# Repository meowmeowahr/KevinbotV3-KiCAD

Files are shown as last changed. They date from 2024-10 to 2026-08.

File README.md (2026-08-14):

# This repository has moved

Kevinbot Core and the Kevinbot P2 Board have split into separate repositories, and are now located in the [Kevinbot Robotics](https://github.com/Kevinbot-Robotics) organization.

## Kevinbot Core (aka RevB)

https://github.com/Kevinbot-Robotics/kevinbot_core

## Kevinbot P2 Board (aka RevA)

https://github.com/Kevinbot-Robotics/kevinbot_p2_board

## PCBWay

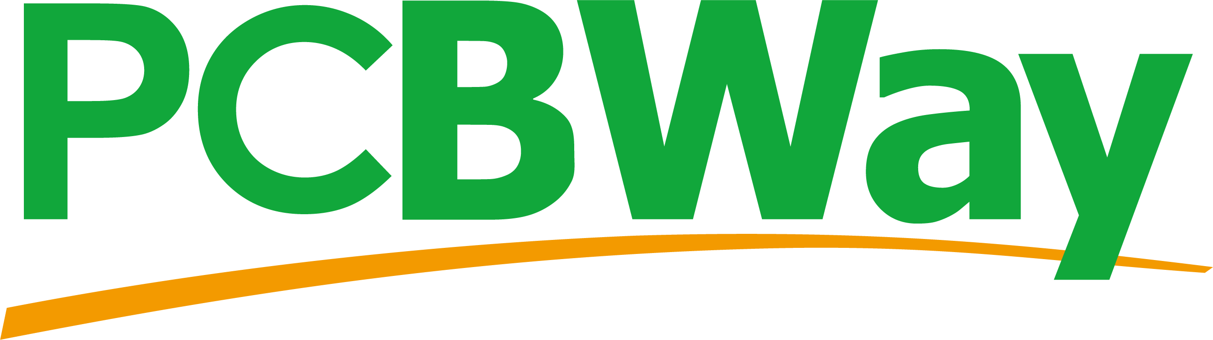
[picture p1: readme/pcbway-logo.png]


Thanks to PCBWay for providing high-quality PCB prototypes.

I would recommend them for any of your PCB needs. They offer fast turnaround and shipping.

[Get a Quote Here](https://www.pcbway.com/orderonline.aspx)

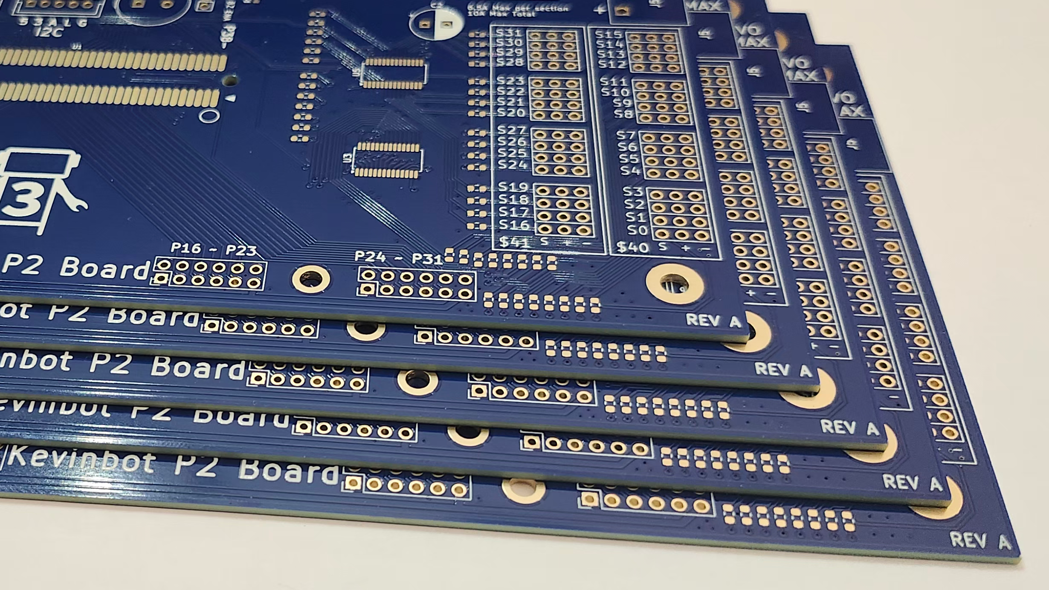
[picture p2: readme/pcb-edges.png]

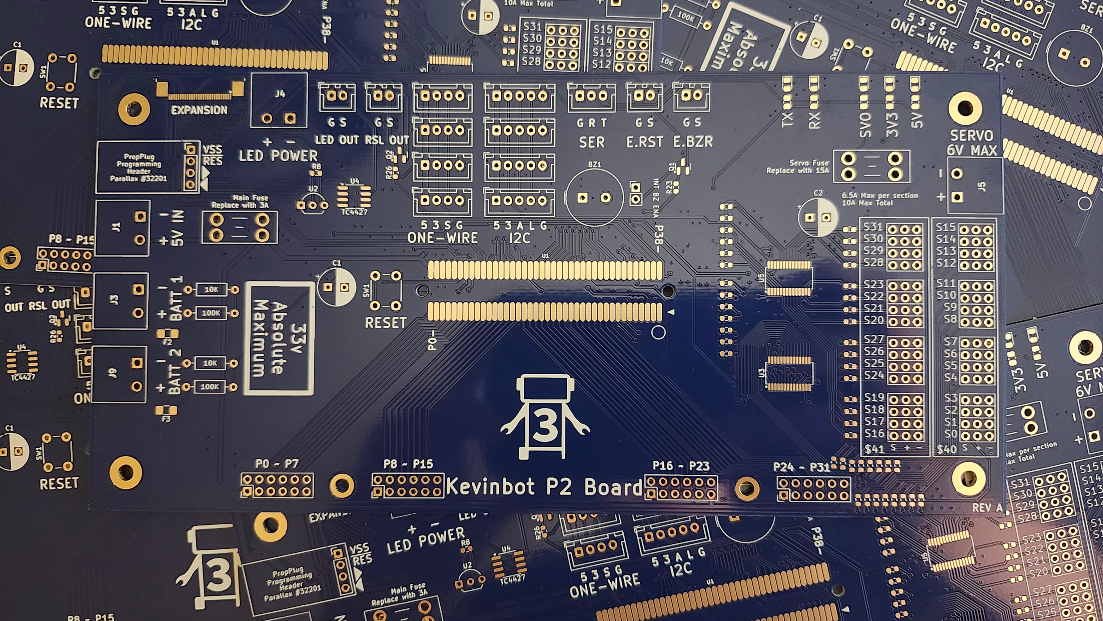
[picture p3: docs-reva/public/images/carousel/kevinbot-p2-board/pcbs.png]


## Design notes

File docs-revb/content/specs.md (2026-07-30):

---
title: "Specifications"
editURL: https://github.com/meowmeowahr/KevinbotV3-KiCAD/edit/RevB/docs/specs.md
cascade:
  type: docs
weight: 3
---

## Electrical Characteristics

| Parameter | <div style="width:200px">Name</div>  | <div style="width:100px">Conditions</div> | Min | Typical | Max | Unit |
| --- | --- | --- | --- | --- | --- | ---- |
| V<sub>IN</sub> | Input Voltage | | 6 | - | 40 | V |
| I<sub>DD</sub> | Input Current Draw | V<sub>IN</sub> = 6V<br>V<sub>IN</sub> = 23V<br>V<sub>IN</sub> = 40V | - | - | 5.30<br>1.40<br>0.82 | A |
| V<sub>IN(VM)</sub> | Voltmeter Input Voltage | | - | - | 60 | V |
| I<sub>DD(VM)</sub> | Voltmeter Current Draw | V<sub>IN(VM)</sub> = 60V<br>V<sub>IN(VM)</sub> = 12V<br>V<sub>IN(VM)</sub> = 6V | - | 315.8<br>63.2<br>31.6 | - | µA |
| V<sub>IN(SV)</sub> | Servo Input Voltage | | - | - | 24 | V |
| I<sub>OUT(SV)</sub> | Servo Max Total Output Current | | - | - | 12 | A |
| I<sub>OUT(SVCH)</sub> | Servo Max Per Channel Output Current | | - | - | 3 | A |

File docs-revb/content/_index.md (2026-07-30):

---
title: "Kevinbot Core"
editURL: https://github.com/meowmeowahr/KevinbotV3-KiCAD/edit/RevB/docs-revb/content/_index.md
cascade:
  type: docs
next: diagram
---

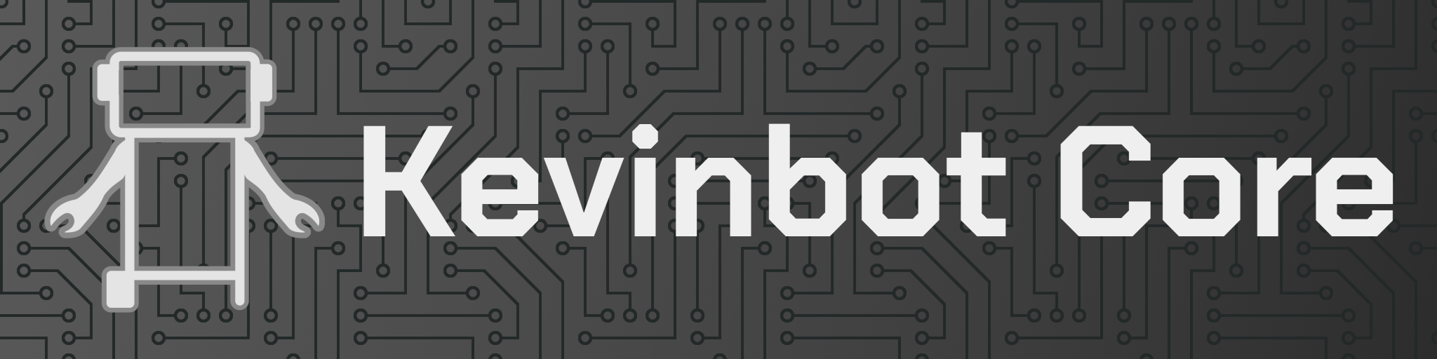
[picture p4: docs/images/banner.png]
Logo banner


<style>
/* hide title */
article > main > div.content > :nth-child(1) {
    display: none;
}
</style>

{{< carousel gallery="kevinbot-core" >}}

{{< hextra/hero-button text="View Project on GitHub" link="https://github.com/meowmeowahr/KevinbotV3-KiCAD/tree/RevB" >}}

The Kevinbot Core is a [Parallax Propeller 2 Edge](https://www.parallax.com/product/p2-edge-module/) Breakout 
Board catered for robotics use.
Originally designed only for use in Kevinbot v3, the board can be used for any P2-based robotics project.

## Revision Comparisons

| Feature | RevA | RevB |
| :--- | :--- | :--- |
| MCU | Parallax P2 | Parallax P2 |
| Input Voltage | 5V | 6V ~ 40V |
| I/O Pins | 32 (Accessory), 20 (Expansion) | 32 (Accessory) |
| Servo Ports | 32 (Up to 6V power) | 16 (Up to 24V power) |
| Interfaces | UART, I2C, One-Wire | RS-422 (_or_ UART), I2C, One-Wire |
| Serial Interface | ✅ UART | ✅ RS-422 (_or_ UART) |
| I2C Interface | ✅ 4 Ports | ✅ 1 Port with Active Pullup |
| One-Wire Interface | ✅ 4 Ports | ✅ 1 Port with Active Pullup |
| Programming | PropPlug Interface | USB-C _or_ External |
| Inbuilt Sensors | DS18B20 Thermo | DS18B20 Thermo |
| Voltmeters | 2x Up to 33v | 2x Up to 60v + Input meter (Up to 40v) |
| Error Buzzer | ✅ | ✅ |
| NeoPixel Output | ✅ | ✅ |
| Status Light Output | ✅ | ✅ |
| Reset Button and Header | ✅ | ✅ |

## Specifications

* Compatible with standard P2 Edge (will not work with the 32 MB option)
* USB-C FTDI Programming Interface
* 16 Servo Outputs
* One-Wire with Active Pullup
* I2C with Active Pullup
* RS-422
* Status Light Port
* Internal Input Voltmeter (1v ~ 40v) + Two External Voltmeters (1v ~ 60v)
* Level-Shifted Addressable LED port
* Four 2x6 P2 accessory headers
* Internal and External Error Buzzer
* Reset Button and External Reset button port
* Internal DS18b20 thermometer
* Fully Open Source Design

## License

All hardware is licensed under the CERN-OHL-S-2.0 license. 
Documentation and media (images) are licensed under a CC-BY-SA-4.0 license.

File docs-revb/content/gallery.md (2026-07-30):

---
title: "Image Gallery"
editURL: https://github.com/meowmeowahr/KevinbotV3-KiCAD/edit/RevB/docs-revb/content/gallery.md
cascade:
  type: docs
weight: 7
---

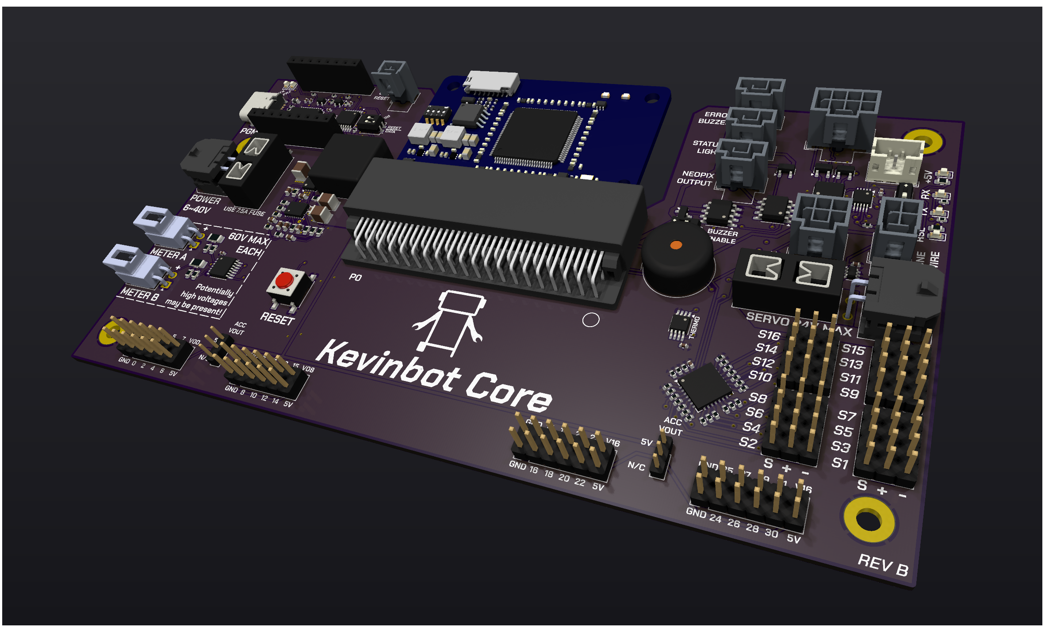
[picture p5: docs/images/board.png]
tbd


## 3D Renders

### Black

{{< tabs >}}
    {{< tab name="Angle 1" >}}
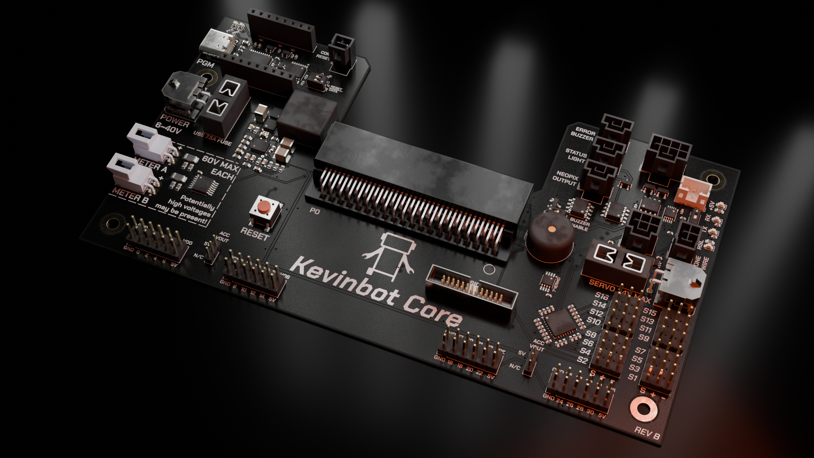
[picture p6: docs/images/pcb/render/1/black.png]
    
    {{< /tab >}}
    {{< tab name="Angle 2" >}}
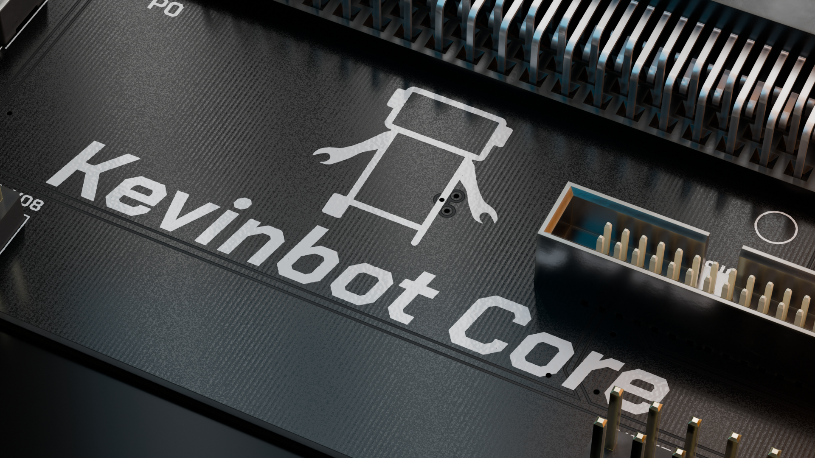
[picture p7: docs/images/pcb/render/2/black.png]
    
    {{< /tab >}}
{{< / tabs >}}

### White

{{< tabs >}}
    {{< tab name="Angle 1" >}}
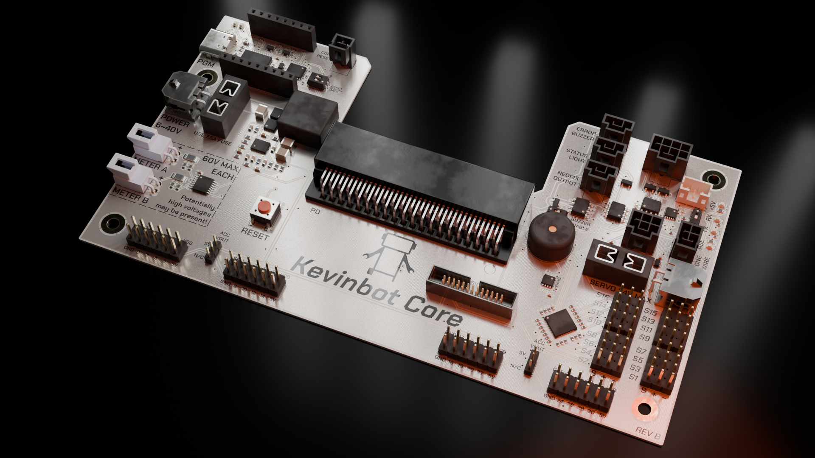
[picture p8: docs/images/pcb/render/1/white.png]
    
    {{< /tab >}}
    {{< tab name="Angle 2" >}}
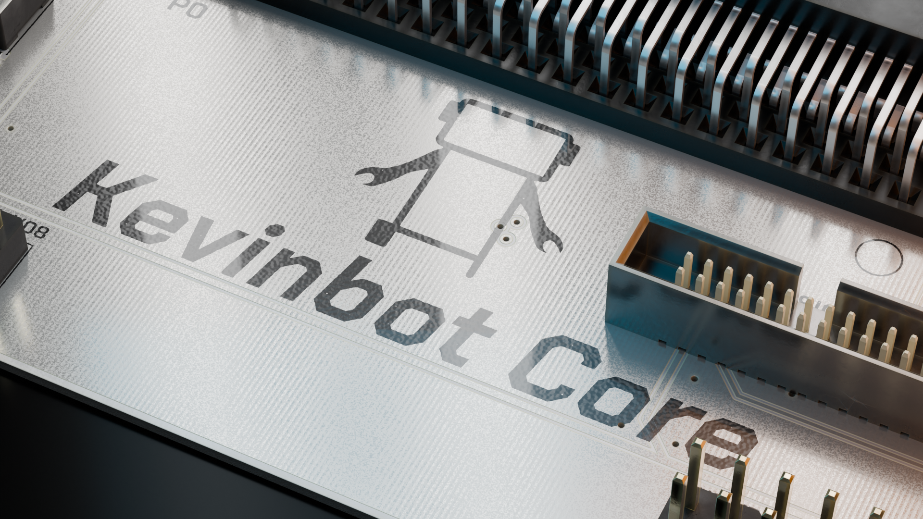
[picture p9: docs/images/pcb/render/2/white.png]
    
    {{< /tab >}}
{{< / tabs >}}

### Blue

{{< tabs >}}
    {{< tab name="Angle 1" >}}
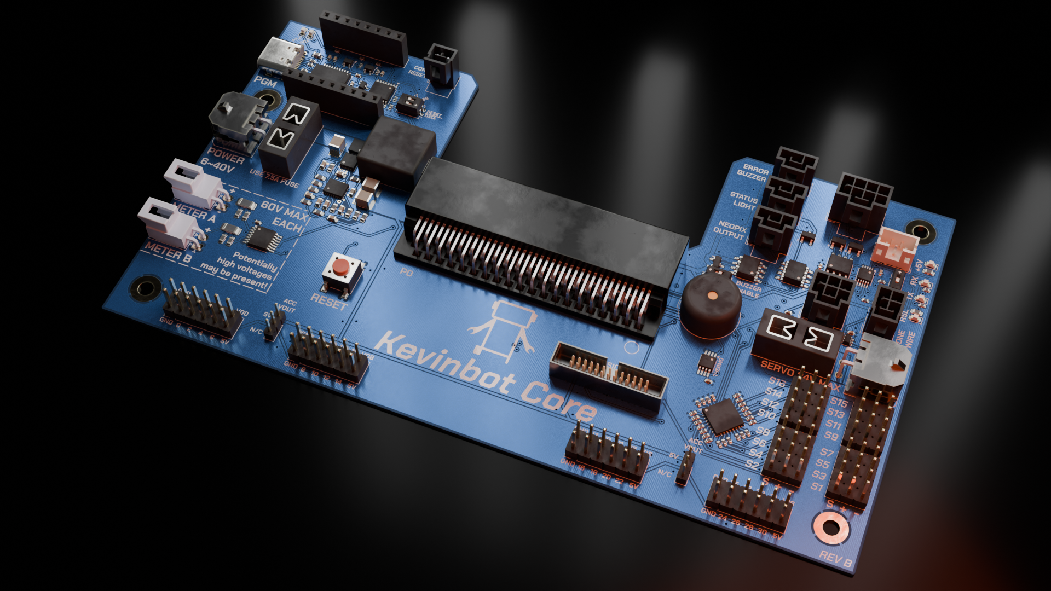
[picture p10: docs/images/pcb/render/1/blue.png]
    
    {{< /tab >}}
    {{< tab name="Angle 2" >}}
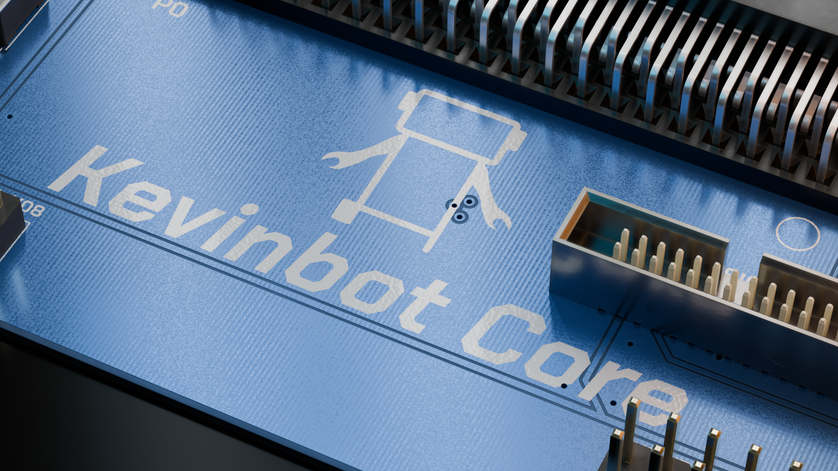
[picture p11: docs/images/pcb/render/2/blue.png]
    
    {{< /tab >}}
{{< / tabs >}}

### Green

{{< tabs >}}
    {{< tab name="Angle 1" >}}
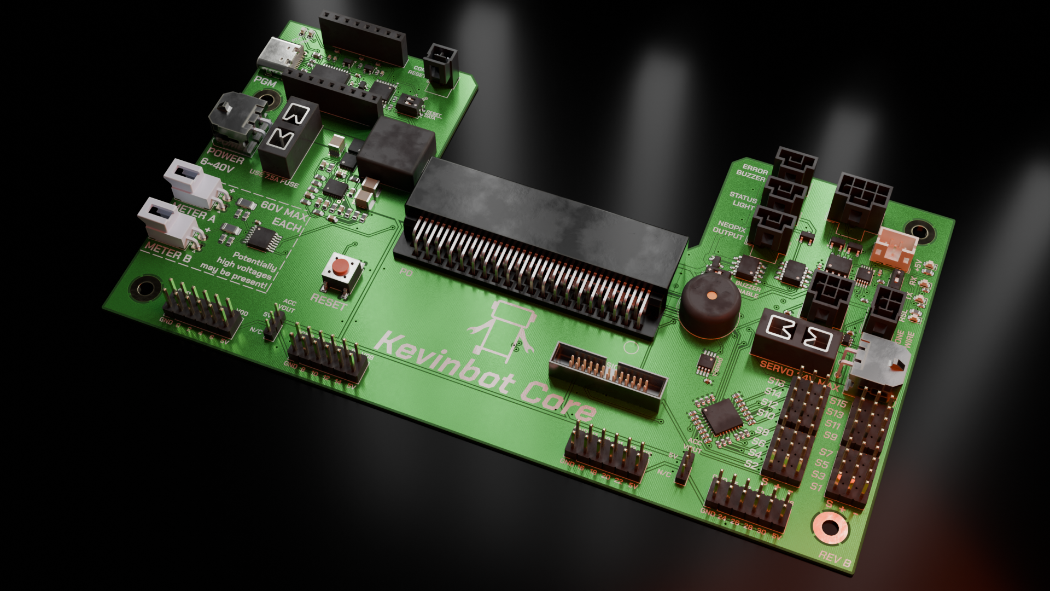
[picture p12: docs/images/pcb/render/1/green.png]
    
    {{< /tab >}}
    {{< tab name="Angle 2" >}}
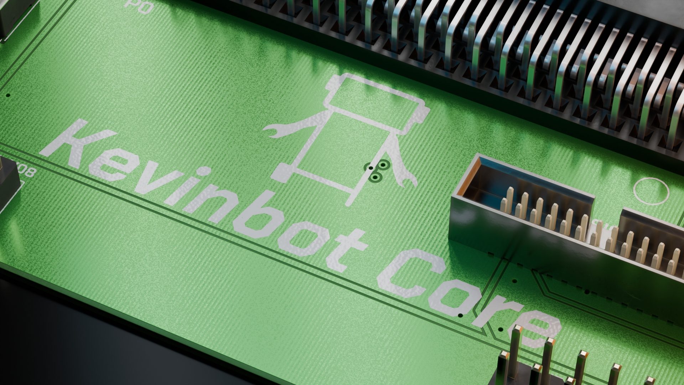
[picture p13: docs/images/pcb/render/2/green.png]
    
    {{< /tab >}}
{{< / tabs >}}

### Red

{{< tabs >}}
    {{< tab name="Angle 1" >}}
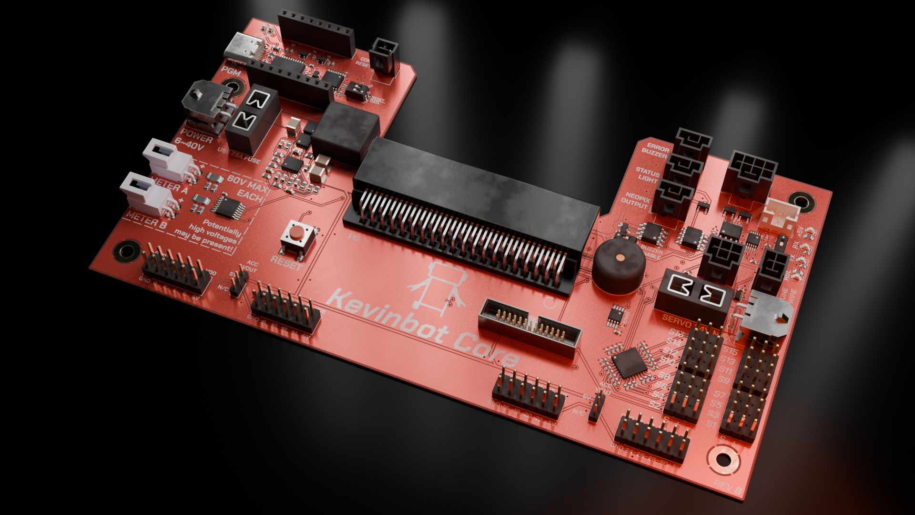
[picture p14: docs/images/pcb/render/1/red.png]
    
    {{< /tab >}}
    {{< tab name="Angle 2" >}}
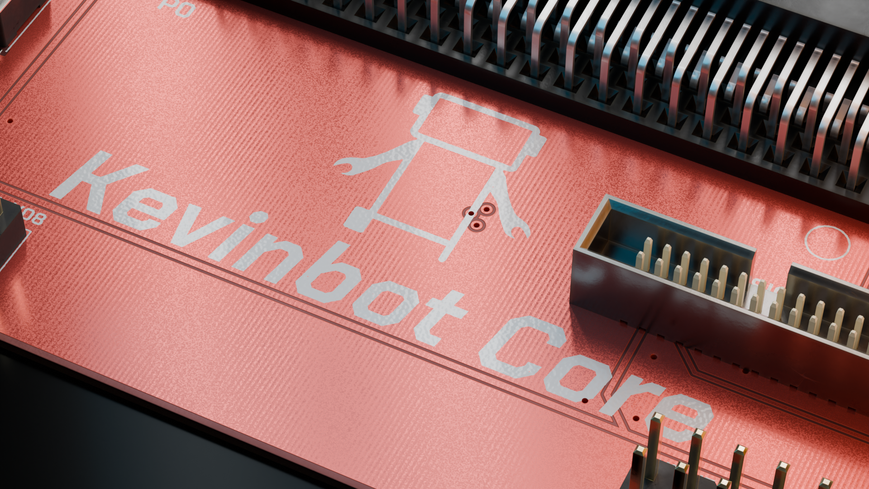
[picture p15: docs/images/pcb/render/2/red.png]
    
    {{< /tab >}}
{{< / tabs >}}

### Purple

{{< tabs >}}
    {{< tab name="Angle 1" >}}
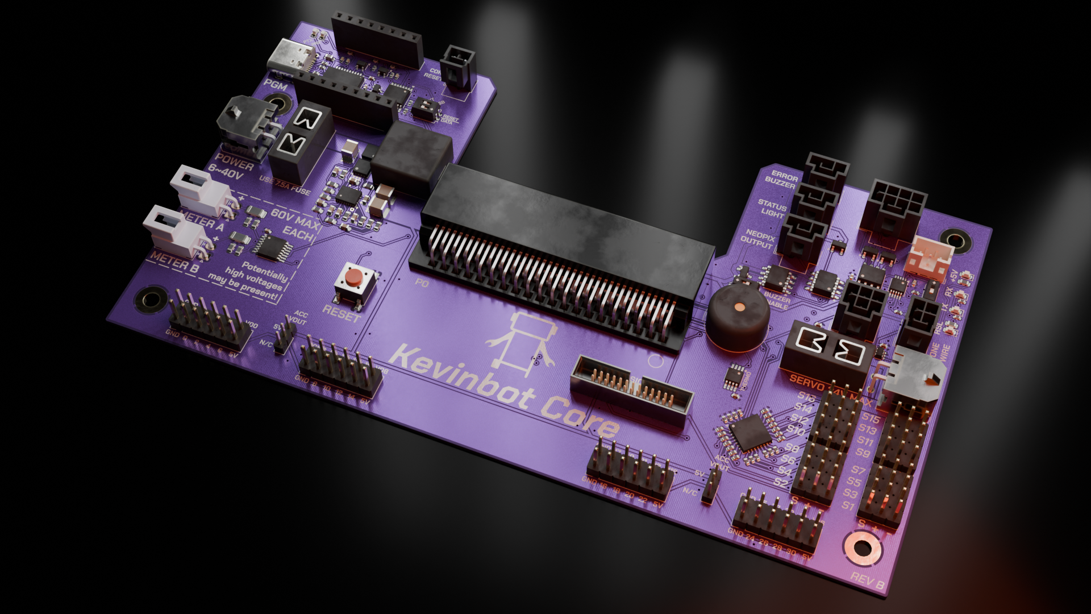
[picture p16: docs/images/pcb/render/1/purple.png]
    
    {{< /tab >}}
    {{< tab name="Angle 2" >}}
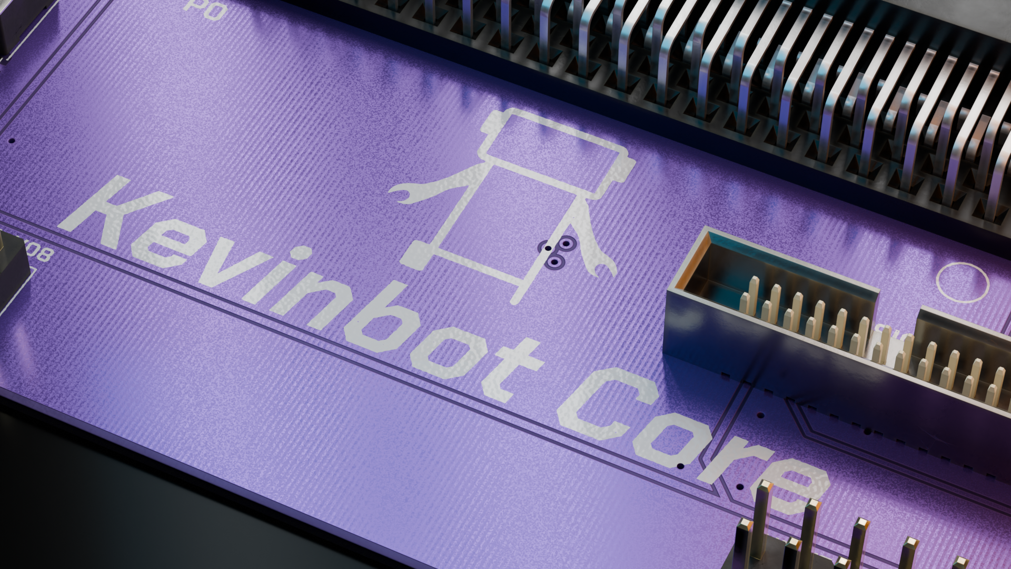
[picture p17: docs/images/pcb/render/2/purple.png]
    
    {{< /tab >}}
{{< / tabs >}}

### Yellow

{{< tabs >}}
    {{< tab name="Angle 1" >}}
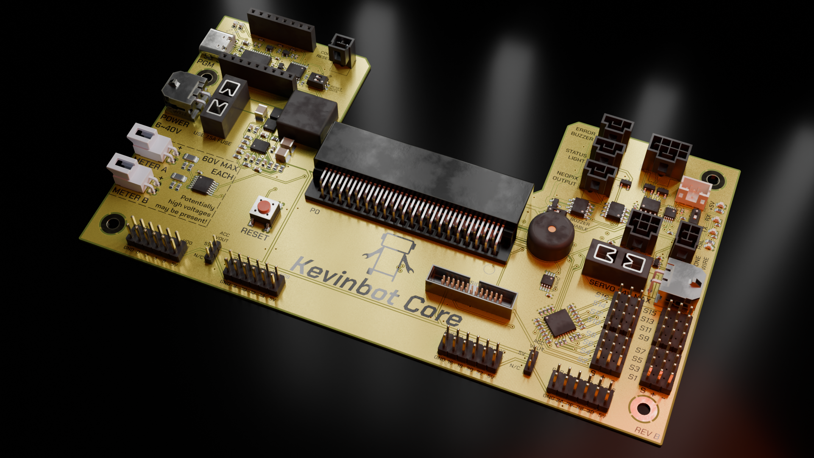
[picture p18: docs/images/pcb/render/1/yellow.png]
    
    {{< /tab >}}
    {{< tab name="Angle 2" >}}
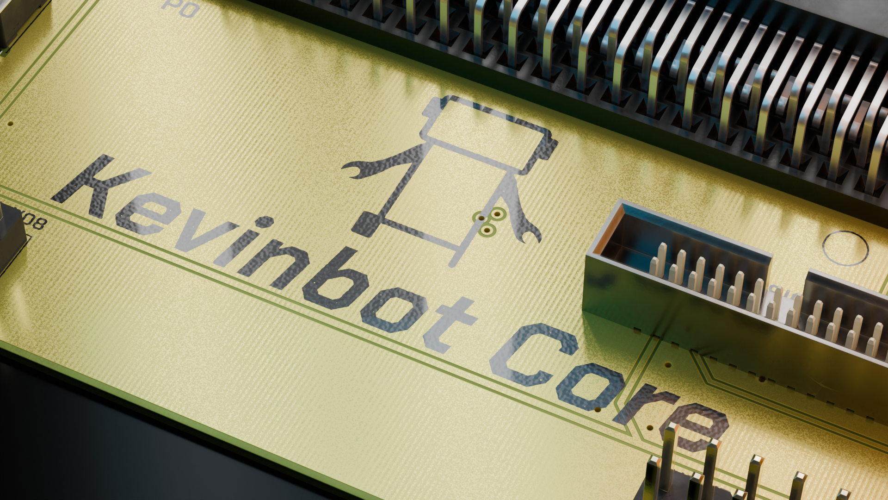
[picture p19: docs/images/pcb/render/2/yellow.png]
    
    {{< /tab >}}
{{< /tabs >}}

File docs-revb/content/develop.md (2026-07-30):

---
title: "Development"
editURL: https://github.com/meowmeowahr/KevinbotV3-KiCAD/edit/RevB/docs/develop.md
cascade:
  type: docs
weight: 8
---

## Technical

### Board and Schematics

The project utilizes KiCAD 9.0.1 or later.
Download it [here](https://www.kicad.org/download/).

The project file is located at `P2 Kevinbot Board.kicad_pro`

#### Fonts

The Kevinbot Core PCB design utilizes some non-standard fonts. They must be installed in the system to function correctly within KiCAD.

Restart KiCAD after installing fonts.

All utilized fonts are licensed under the [OFL (SIL Open Font License)](https://openfontlicense.org/)

[Chakra Petch :fontawesome-solid-arrow-up-right-from-square:](https://fonts.google.com/specimen/Chakra+Petch){ .md-button }

## Documentation

The Kevinbot Core documentation is built with [Hugo](https://gohugo.io/).

## WireViz

The Kevinbot Core documentation utilizes WireViz for cable harness visualizations.

### Install

Install Python dependencies using `pip`

```bash
pip install wireviz
```

### Develop

All WireViz YAML sources are located in the `wireviz/` directory.

Generated images are located in the `docs/images/wireviz/` directory.

Images can be generated with the `gen-harness` bash script.
Run it with the following.

```bash
bash tools/gen-harness.sh
```

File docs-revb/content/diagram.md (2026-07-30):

---
title: "Board Diagram"
editURL: https://github.com/meowmeowahr/KevinbotV3-KiCAD/edit/RevB/docs/diagram.md
cascade:
  type: docs
prev: /robotics/kevinbot-core
weight: 1
---

Numbered board diagram

## #1 - P2 Edge Socket
Compatible with Parallax P2 Edge ([https://www.parallax.com/product/p2-edge-module/](https://www.parallax.com/product/p2-edge-module/))

{{< callout type="warning" >}}
Kevinbot Core is **NOT** compatible with the *P2-EC32MB*
{{< /callout >}}

## #2 - Power Input
Kevinbot Core can take anywhere from 6v to 40v. Input is protected by a 7.5A fuse.
<br>
Operating outside these limits may cause damage to the board.

## #3 - USB-C Programming Header

FTDI Prop-Plug compatible programming interface.
<br>
Both [#21 DIP Switches](#21---programmer-selector-switches) must be set to **USB** to enable the USB programmer.

## #4 - Reset Button

Press the button to manually reset the P2

## #5 - Reset Header

Connect both pins to reset the P2.
<br>
Compatible with [Molex 1x2 Nano-Fit connector housings](https://www.molex.com/en-us/products/part-detail/1053071202)

## #6 - P2 EVAL Accessory Headers

Compatible with P2-EVAL accessories. Each header exposes 8 I/O pins, 3.3v, GND, and 5v.

## #7 - Accessory Header 5V Enable

Jumper selector to enable 5V on [#6 accessory headers](#6---p2-eval-accessory-headers)

## #8 - Expansion Port

Reserved for future use.

## #9 - Buzzer

User-controllable buzzer for errors, status, etc...

## #10 - Status Led Port

5v signal level LED header.

{{< callout type="note" >}}
It is not recommended to use this for addressable LEDs due to potential slow switching times.
{{< /callout >}}

## #11 - Addressable LED Output

5v signal level addressable LED output.

## #12 - RS-422 Input/Output

Serial over 2 twisted pairs. 

{{< callout type="note" >}}
The UART Enable Switch must be set to the lower position to enable the RS-422 port.
{{< /callout >}}

## #13 - UART Input/Output

3.3v UART RX/TX lines.

{{< callout type="note" >}}
The UART Enable Switch must be set to the upper position to enable the UART port.
{{< /callout >}}

## #14 - I2C Port

3.3v I2C SDA/SCL lines.

## #15 - One-Wire Port

3.3v One-Wire data.

## #16 - Servo Power Input

Up to 24v servo power input. Protected by a 15A fuse.
<br>
Operating outside these limits may cause damage to the board.

## #17 - Servo (PWM) Headers

16 PWM headers. Uses a PCA9685 to drive the outputs.

## #18 - Thermometer

DS18B20 One-Wire thermometer.
<br>
Internally connected to the same One-Wire bus as the [One-Wire Port](#15---one-wire-port)

## #19 - Programmer Indicator LEDs

FTDI activity LEDs.

## #20 - External Programmer Headers

Connection to external programming device. Exposes the P2's Rx/Tx, and flash chip SPI lines.
<br>
Both [#21 DIP Switches](#21---programmer-selector-switches) must be set to **EXT** to enable the USB programmer.

## #21 - Programmer Selector Switches

Switch between the USB-C and external programming headers.

## #22 - External Error Buzzer Port

External buzzer port with 5v signal level.

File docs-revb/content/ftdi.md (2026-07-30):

---
title: "FTDI Configuration"
editURL: https://github.com/meowmeowahr/KevinbotV3-KiCAD/edit/RevB/docs/ftdi.md
cascade:
  type: docs
weight: 5
---

The onboard FT231XS UART-to-USB converter requires configuration before it is able to program the P2.
Configuration is done through [FT_PROG](https://ftdichip.com/utilities/#ft_prog)

{{< callout type="warning" >}}
Incorrect usage of FT_PROG may brick the FT231XS chip. Be careful when changing settings.
{{< /callout >}}

## Settings

| Option | Value  |
| :--- | :----- |
| CBUS0 | TXLED  |
| CBUS1 | SLEEP# |
| CBUS2 | TXDEN  |
| CBUS2 | RXLED  |
| USB - MaxPower | 90mA |
| Pull down IO in suspend | True |

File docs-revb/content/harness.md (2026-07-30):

---
title: "Wiring Harnesses"
editURL: https://github.com/meowmeowahr/KevinbotV3-KiCAD/edit/RevB/docs/harness.md
cascade:
  type: docs
weight: 6
---

## Main RS-422 Communication

RS-422 Core<->System Cable Core represents the Kevinbot Core, System represents the main control system

### Cable Options

#### Tensility International Corp 30-02485

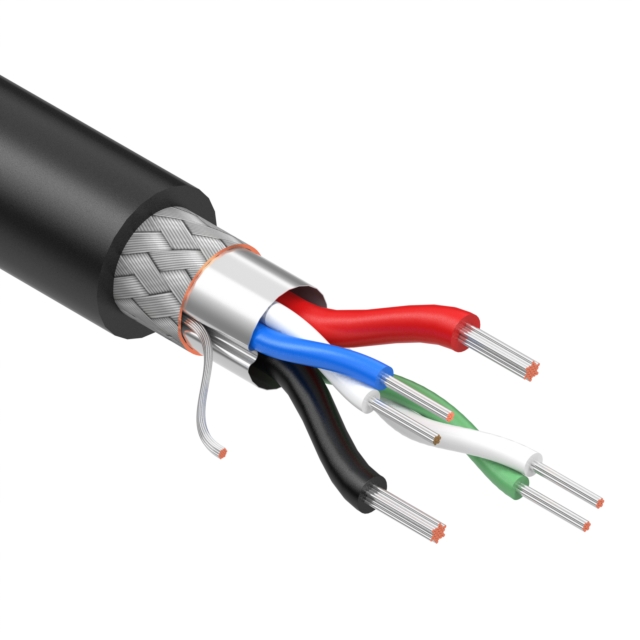
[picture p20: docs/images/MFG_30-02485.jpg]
Tensility International Corp 30-02485


[Digi-Key](https://www.digikey.com/en/products/detail/tensility-international-corp/30-02485/16629555)

The Blue/White Pair corresponds to GN/BU
<br>
The Green/White Pair corresponds to YE/OG
<br>
The Black and Red Wires are **BOTH** connected to GND at both ends
<br>
The Shield is connected at pin 8 of the System end

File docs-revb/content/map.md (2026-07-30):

---
title: "Pin Mappings"
editURL: https://github.com/meowmeowahr/KevinbotV3-KiCAD/edit/RevB/docs/map.md
cascade:
  type: docs
weight: 2
---

tbd

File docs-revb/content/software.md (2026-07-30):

---
title: "Software"
editURL: https://github.com/meowmeowahr/KevinbotV3-KiCAD/edit/RevB/docs/software.md
cascade:
  type: docs
weight: 4
---

## Board-specific applications

[**Kevinbot v3 Core**](https://github.com/meowmeowahr/KevinbotV3-HW-Core)

## General P2 Objects

**jm_ds18b20.spin2**
<br/>
A driver can be found [here](https://www.parallax.com/1-wire-driver-with-ds18b20-temperature-sensor-demo/)

This will work for interfacing with the single sensor on the board, or external sensors via the One-Wire Ports.
You can use the One-Wire scanner tool on the [Kevinbot v3 GitHub Repo](https://github.com/meowmeowahr/KevinbotV3-HW-Core/blob/v3-redesign/KevinbotV3_DS_SerialTool.spin2)

**ka_pca9685.spin2**
<br/>
The driver can be found [here](https://github.com/meowmeowahr/KevinbotV3-HW-Core/blob/v3-redesign/ka_pca9685.spin2)

This will work for the built in 16x servo controller, and any additional servo expansions

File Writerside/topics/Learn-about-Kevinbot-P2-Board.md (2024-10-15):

# Learn about Kevinbot P2 Board

The Kevinbot P2 Board is a [Parallax Propeller 2 Edge](https://www.parallax.com/product/p2-edge-module/) Breakout 
Board catered for robotics use.
Originally designed only for use in Kevinbot v3, the board can be used for any P2-based robotics project.

## Specifications

* Compatible with standard P2 Edge (will not work with the 32 MB option)
* Prop-Plug Programming Interface
* 32 Servo Outputs
* Four One-Wire Ports
* Four I2C Ports
* One Serial UART Port
* One RSL (Status Light) Port
* Two Voltmeters (1v ~ 33v)
* One Level-Shifted WS281X(b) port
* Four 2x6 Way P2 accessory headers
* Internal and External Error Buzzer
* Reset Button and External Reset button port
* Internal DS18b20 thermometer
* Fully Open Source Design

## License

All hardware is licensed under the CERN-OHL-S-2.0 license. 
Documentation and media (images) are licensed under a CC-BY-SA-4.0 license.

## PCBWay

PCBWay

Thanks to PCBWay for providing high-quality and fast PCB prototypes.

I would recommend them for any of your PCB needs. They offer fast turnaround and shipping.

[Get a Quote Here for as low as $5](https://www.pcbway.com/orderonline.aspx)

pcb edges
Kevinbot P2 Board pcb

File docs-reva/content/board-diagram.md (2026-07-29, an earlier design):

---
title: "Board Diagram"
editURL: https://github.com/meowmeowahr/KevinbotV3-KiCAD/edit/RevB/docs-reva/content/board-diagram.md
prev: /robotics/kevinbot-p2-board
next: pin-mappings
weight: 1
---

PCB diagram with numbered elements

## 1. P2 Edge Socket

Parallax Propeller 2 Socket (P2-EC)

{{< callout type="warning" >}}
Not compatible with 32MB RAM upgrade (P2-EC32MB)
{{< /callout >}}

## 2. 5V DC Input
    
Maximum Voltage: **5.25v**

Uses [Phoenix Contact MSTBA style connector](https://www.phoenixcontact.com/en-us/products/pcb-plug-mstb-25-2-st-508-1757019)

## 3. Voltmeter for Battery #1

Do not apply more than **33v** to the input, or you will damage the P2.

Uses [Phoenix Contact MSTBA style connector](https://www.phoenixcontact.com/en-us/products/pcb-plug-mstb-25-2-st-508-1757019)

## 4. Voltmeter for Battery #2
   
Do not apply more than **33v** to the input, or you will damage the P2.

Uses [Phoenix Contact MSTBA style connector](https://www.phoenixcontact.com/en-us/products/pcb-plug-mstb-25-2-st-508-1757019)

## 5. Servo Power Input

Power input for the 32 servo ports

{{< callout type="warning" >}}
Do not exceed 6v on the servo input
{{< /callout >}}

Uses [Phoenix Contact MSTBA style connector](https://www.phoenixcontact.com/en-us/products/pcb-plug-mstb-25-2-st-508-1757019)

## 6. Main fuse

Fuse for 5v rail. Replace it with **3A** ATM mini fuse

## 7. Servo fuse

Fuse for servo rail. Replace it with **15A** ATM mini fuse

{{< callout type="note" >}}
<b>Current Warning</b>
<br>
Exceeding these rating may cause overheating of the board traces and/or connectors
{{< /callout >}}

Servo channel current ratings:

* **10A** Max total current
* **6.5A** Max for each bank of 16
* **3A** Max per channel

## 8. LED Power connector

Power input LED Output.

The voltage going in will be the WS281X(b) signal level

No current will be drawn from this input

{{< callout type="warning" >}}
This is not a fused input. Install a fuse on the input side for safe operation
{{< /callout >}}

## 9. P2 Accessory Ports
   
Parallax-compatible P2-EVAL accessory headers.
Compatible with all accessories.

Accessory List:

* [Universal Motor Driver](https://www.parallax.com/product/universal-motor-driver-p2-add-on-board/)
* [HyperRAM & HyperFlash Add-on](https://www.parallax.com/product/p2-es-eval-board-hyperram-hyperflash-add-on/)
* [HD Audio Add-on set](https://www.parallax.com/product/p2-hd-audio-add-on-set/)
* [RTC Add-on](https://www.parallax.com/product/p2-rtc-add-on-board/)
* [AV Add-on](https://www.parallax.com/product/p2-eval-av-breakout-add-on-board/)
* [Serial Host Add-on](https://www.parallax.com/product/p2-eval-serial-host-add-on-board/)
* [HUB75 Add-on Board](https://www.parallax.com/product/p2-eval-hub75-adapter-board/)
* [LED Matrix](https://www.parallax.com/product/p2-eval-led-matrix-add-on-board/)
* [Serial Device Add-on](https://www.parallax.com/product/p2-eval-serial-device-add-on-board/)
* [Digital Video Out](https://www.parallax.com/product/p2-eval-digital-video-out-add-on-board/)
* [Goertzel Add-on](https://www.parallax.com/product/p2-eval-goertzel-add-on-board/)
* [Mini Proto Add-on](https://www.parallax.com/product/p2-eval-mini-prototyping-add-on-board/)
* [Control Add-on](https://www.parallax.com/product/p2-eval-control-add-on-board/)
* [Proto Add-on](https://www.parallax.com/product/p2-es-eval-protoboard-add-on/)
* [microSD Add-on](https://www.parallax.com/product/p2-microsd-add-on-board/)
* [P2 to MikroBUS Click](https://www.parallax.com/product/p2-to-mikrobus-click-adapter/)
* [WX Adapter](https://www.parallax.com/product/p2-wx-adapter-add-on-board/)

## 10. I2C Ports

Four I<sup>2</sup>C Ports on a common bus

Refer to [Pin Mappings](../pin-mappings) for the internal connections

5v, 3.3v, SDA, SCL, GND starting from the PropPlug side

{{< callout type="warning" >}}
Do not mix-and-match any of the 3.3v rails.
They have the same voltage, but connecting them may result in noisy analog inputs.
{{< /callout >}}

## 11. One-Wire Ports

4 One-Wire Ports on a common bus

Refer to [Pin Mappings](../pin-mappings) for the internal connections

5v, 3.3v, DATA, GND starting from the PropPlug side

{{< callout type="warning" >}}
Do not mix-and-match any of the 3.3v rails.
They have the same voltage, but connecting them may result in noisy analog inputs.
{{< /callout >}}

## 12. LED Output Port

LED Port intended for a single data wire addressable LED segment (such as WS2812b, WS2811, etc...)

Logic level is shifted to the [input](#8-led-power-connector) voltage

## 13. RSL Output Port

The RSL port is intended for a robot status light.
For example, a light that turns on when motors are enabled

Output Voltage: 5v
<br/>
Max Output Current: 1.3A

## 14. UART Communication Port

This port is intended
to be used as a serial communication link between the P2 Board and a main processor like a Raspberry Pi,
or another Kevinbot P2 Board.
While using this port is entirely optional, it may be required for more complex applications.

{{< callout type="tip" >}}
Using shielded cable is recommended at higher data rates
{{< /callout >}}

## 15. External Reset Button Port

This port is for an external PC-like reset button.
A connection between the two pins will result in the CPU restarting.

## 16. External Error Buzzer Port

This port is for a software-controlled external Piezo Buzzer.

Output Voltage: 5v
<br/>
Max Output Current: 1.3A

## 17. Reset Button

Pressing the button will result in the CPU and code execution restarting.

## 18. LED Indicators

Indicates power rail statuses and UART port activity.

Light meanings:
<br/>

```Ini
TX  = UART transmitting
RX  = UART receiving

SVO = Servo power rail
3V3 = P2 V24 rail
5V  = 5V Input rail
```

## 19. PropPlug programming interface

Header for programming the P2. Designed for use with a [Parallax Prop Plug](https://www.parallax.com/product/prop-plug/)

## 20. Internal DS18B20 thermometer

{{< callout type="warning" >}}
Every Kevinbot P2 Board will have a different serial number identifier for the thermometer.
It is required to know the serial number if you have any devices connected to the [One-Wire ports](#11-one-wire-ports)
{{< /callout >}}

## 21. Second Servo Bank

This is the second bank of servo ports (S16 ~ S31)
They are connected to a PCA9685 at I<sup>2</sup>C address `0x41`

Each port has a maximum rating of 3A
<br/>
The whole bank has a rating of 6.5A

## 22. First Servo Bank

This is the first bank of servo ports (S0 ~ S15)
They are connected to a PCA9685 at I<sup>2</sup>C address `0x40`

Each port has a maximum rating of 3A
<br/>
The whole bank has a rating of 6.5A

## 23. Ground test points

These ground points can be invaluable when debugging hardware. Clip your oscilloscope ground to them and debug away!

## 24. Battery Input Polyfuses

These fuses are for the battery voltmeters.
They auto-reset after tripped.
They should never trip unless the board or P2 is damaged in some way.

## 25. Error Buzzer

This is a piezo buzzer intended for error tones.
In the standard [Kevinbot code](https://github.com/meowmeowahr/KevinbotV3-HW-Core),
it will play a startup chime, and continuously beep if an error has occurred.

## 26. Error Buzzer Enabler

Jumper icon
Jumper icon

This jumper should be installed to enable the internal error buzzer.
If the jumper is not installed, the external buzzer port will still be active.

## 27. Expansion connector

This connector is reserved for future use.
A pinout is provided [here](../pin-mappings)

<style>
.light-only {
  display: block;
}

.dark-only {
  display: none;
}

.dark .light-only,
html.dark .light-only {
  display: none;
}

.dark .dark-only,
html.dark .dark-only {
  display: block;
}
</style>

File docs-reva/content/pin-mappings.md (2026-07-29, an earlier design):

---
title: "Pin Mappings"
editURL: https://github.com/meowmeowahr/KevinbotV3-KiCAD/edit/RevB/docs-reva/content/pin-mappings.md
prev: board-diagram
weight: 2
---

## Board Maps

| Pin Function | Board Pin |
|---|---|
| Exposed Accessory I/O | P0~P31 |
| Test Point on Back | P32 |
| Test Point on Back | P33 |
| WS281X(b) LED Output  | P34 |
| UART TX Output | P35 |
| UART RX Input | P36 |
| Voltmeter #1 Input | P37 |
| Voltmeter #2 Output | P38 |
| One-Wire Data Line | P39 |
| Error Buzzer | P40 |
| I2C SDA | P41 |
| I2C SCL | P42 |
| Expansion FFC I/O | P43~P63 |
| Robot Status Light | P56/LED1  |
| Programming TXD | P62 |
| Programming RXD | P63 |

## Expansion header maps

PCB view of Flat Flex Connector
3D view of Flat Flex Connector

From right (servo output) side:

| Pin | Signal | Pin | Signal |
|-----|---|-----|---|
|  1  | GND | 15  | P2_P55 |
|  2  | GND | 16  | P2_P56 |
|  3  | P2_P43 | 17  | P2_P57 |
|  4  | P2_P44 | 18  | P2_P58 |
|  5  | P2_P45 | 19  | P2_P59 |
|  6  | P2_P46 | 20  | P2_P60 |
|  7  | P2_P47 | 21  | P2_P61 |
|  8  | P2_P48 | 22  | P2_P62 (TXD/Prog) |
|  9  | P2_P49 | 23  | P2_P63 (RXD/Prog) |
| 10  | P2_P50 | 24  | P2_RESn (Reset) |
| 11  | P2_P51 | 25  | P2_V48 |
| 12  | P2_P52 | 26  | P2_V56 |
| 13  | P2_P53 | 27  | 5V |
| 14  | P2_P54 | 28  | 5V |

## P2 Accessory header maps

PCB view of P2 Accessory Connectors
3D view of P2 Accessory Connectors

These ports are compatible with all the Parallax P2-EVAL accessories.

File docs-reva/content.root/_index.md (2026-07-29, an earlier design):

[Go to Docs](/robotics/kevinbot-p2-board/)

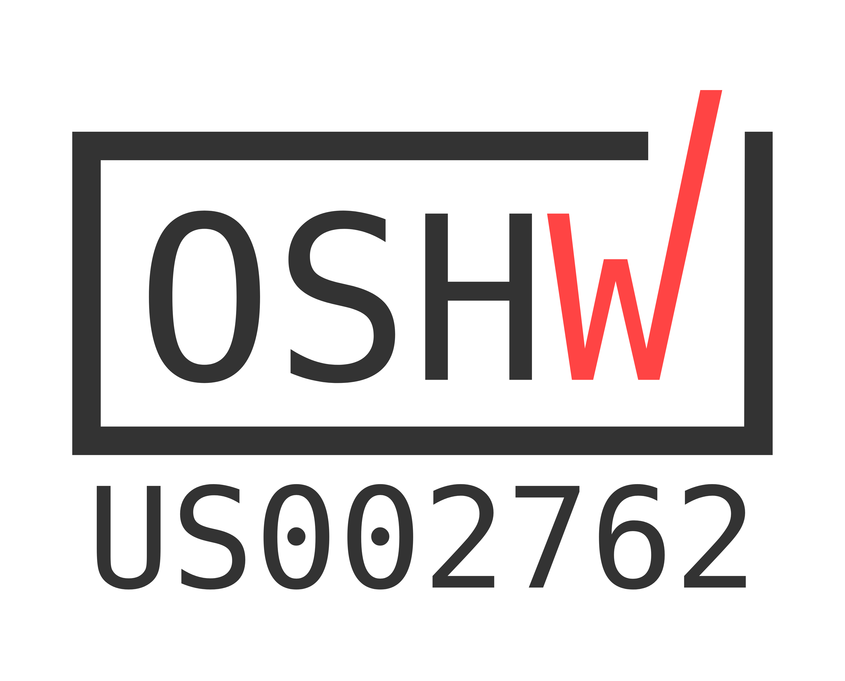
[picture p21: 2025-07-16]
certification-mark-stacked.png

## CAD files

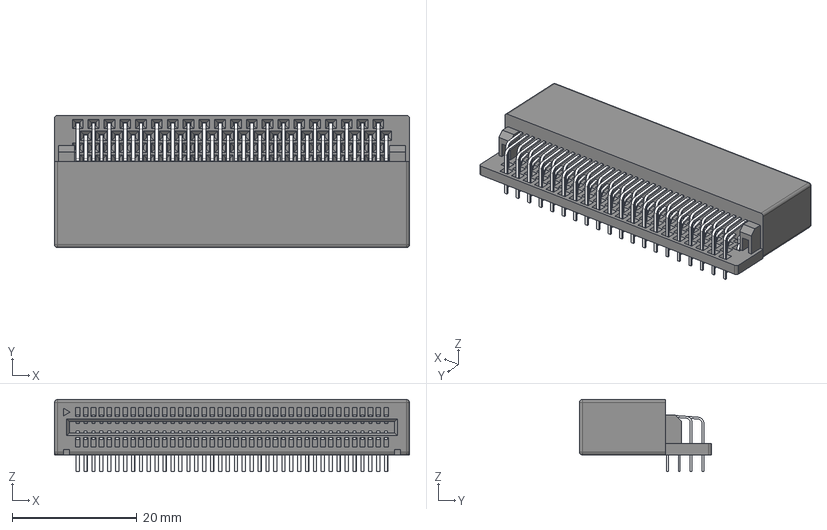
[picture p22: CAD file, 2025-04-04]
Parallax-P2.3dmodels/CardEdge80p127_RA_TH_10156.step.stp
57.0 x 21.3 x 11.6 mm
Housing
PinAligner
Pin4 x 20
Pin3 x 20
Pin2 x 20
Pin1 x 20

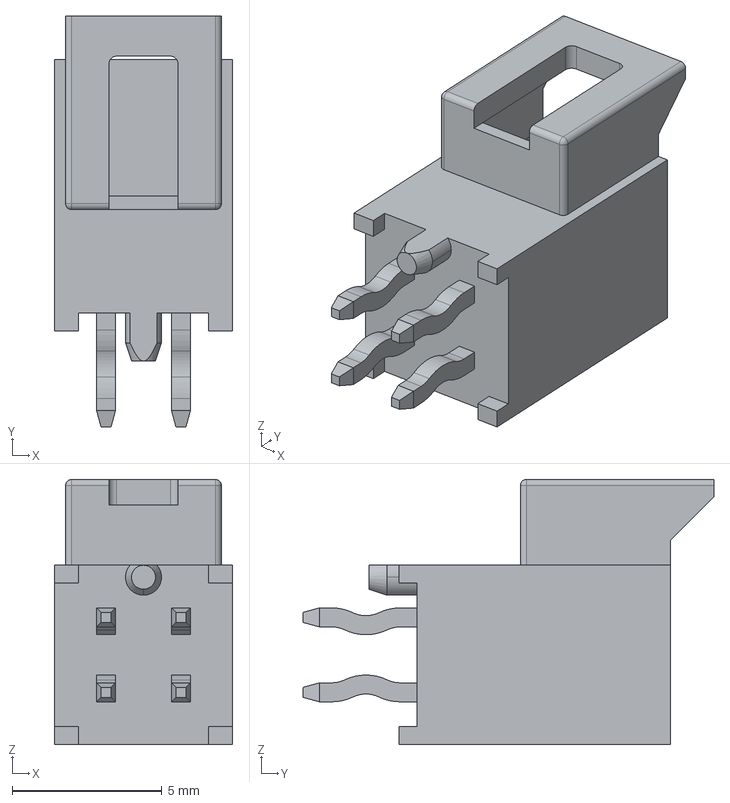
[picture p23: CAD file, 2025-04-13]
Molex.3dmodels/1053101104--3DModel-STEP-510211.STEP
5.94 x 13.7 x 8.84 mm

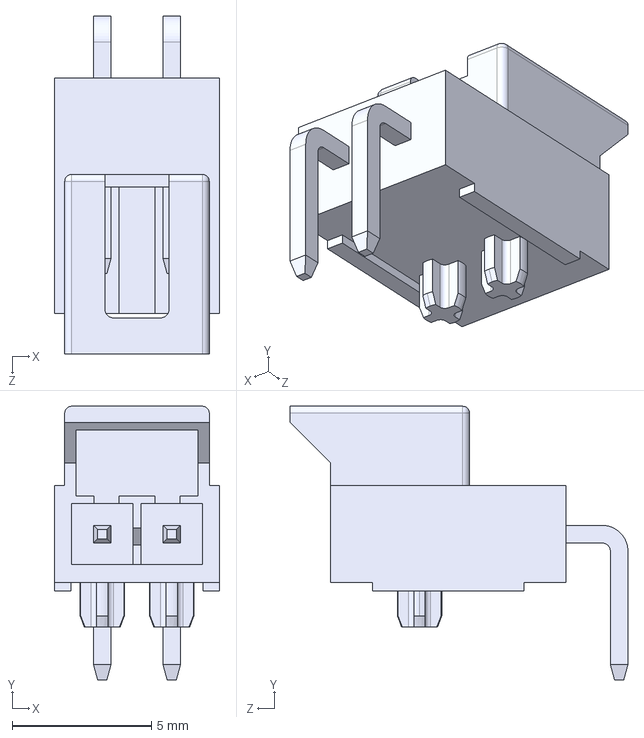
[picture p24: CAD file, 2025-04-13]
Molex.3dmodels/1053132102--3DModel-STEP-510211.STEP
5.94 x 9.84 x 12.2 mm

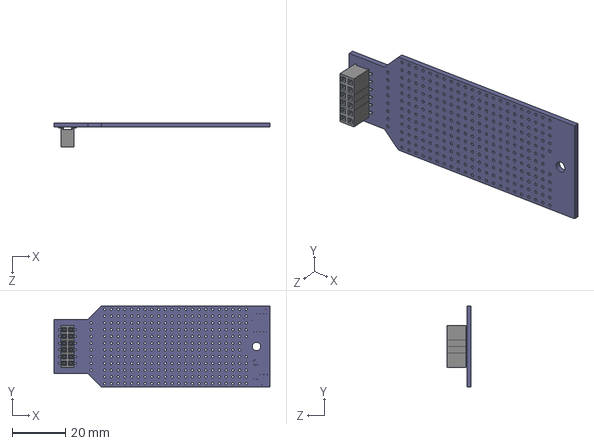
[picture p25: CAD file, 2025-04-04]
Parallax-P2.3dmodels/64005-RevA-P2-PrototypeBoard-Addon.step
81.3 x 30.5 x 9.11 mm
Board_64005-RevA-P2-PrototypeBoard-Addon
hdrf-2x6s_2.54x2.54_16x7

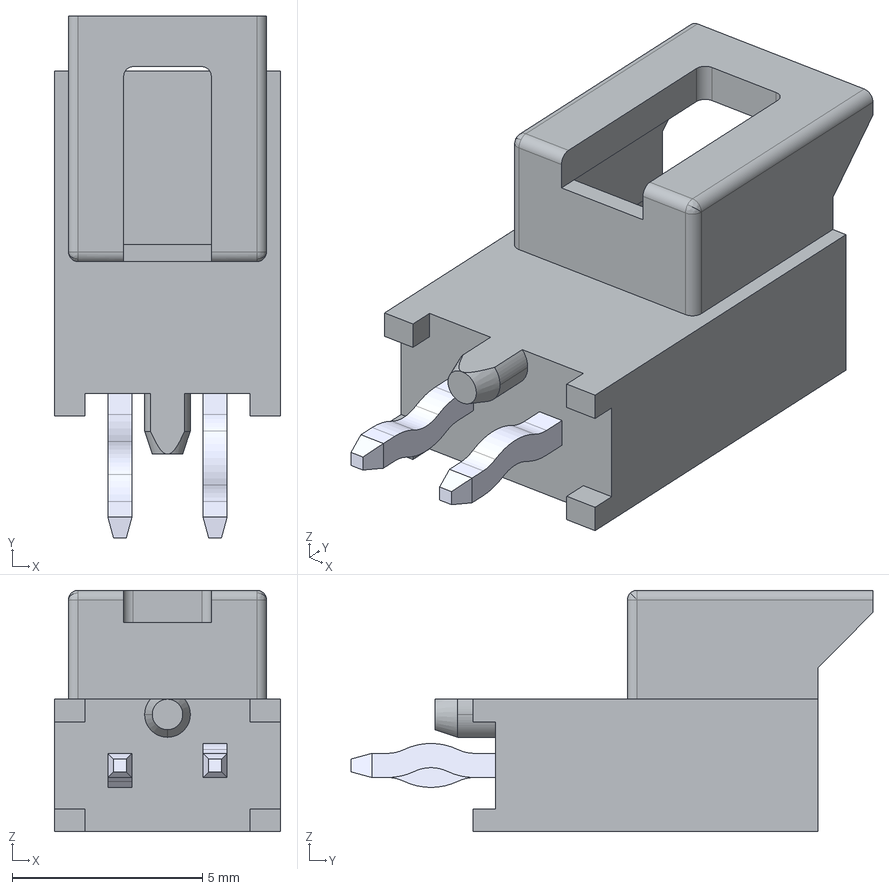
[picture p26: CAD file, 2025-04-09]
Molex.3dmodels/1053091102--3DModel-STEP-510211.STEP
5.94 x 13.7 x 6.34 mm

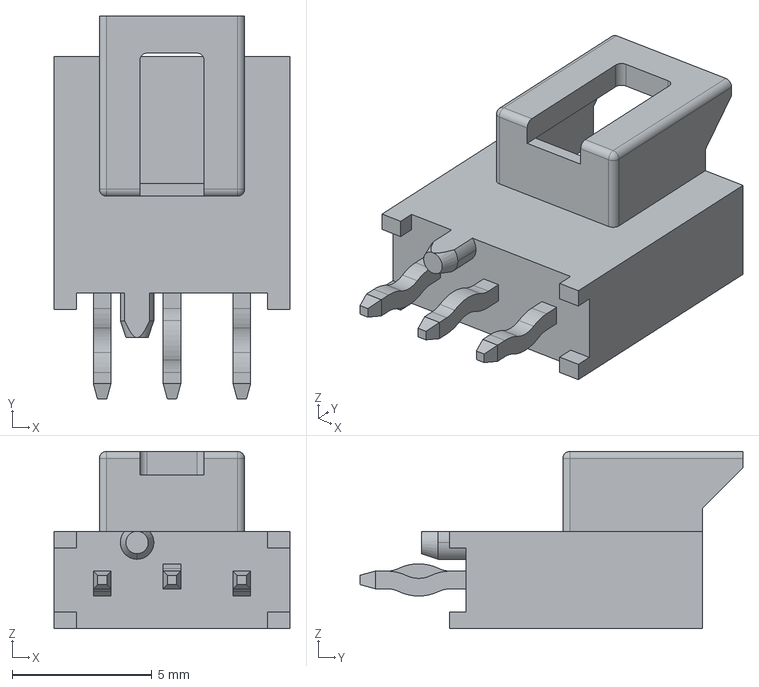
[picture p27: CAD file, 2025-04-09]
Molex.3dmodels/1053091103--3DModel-STEP-510211.STEP
8.44 x 13.7 x 6.34 mm

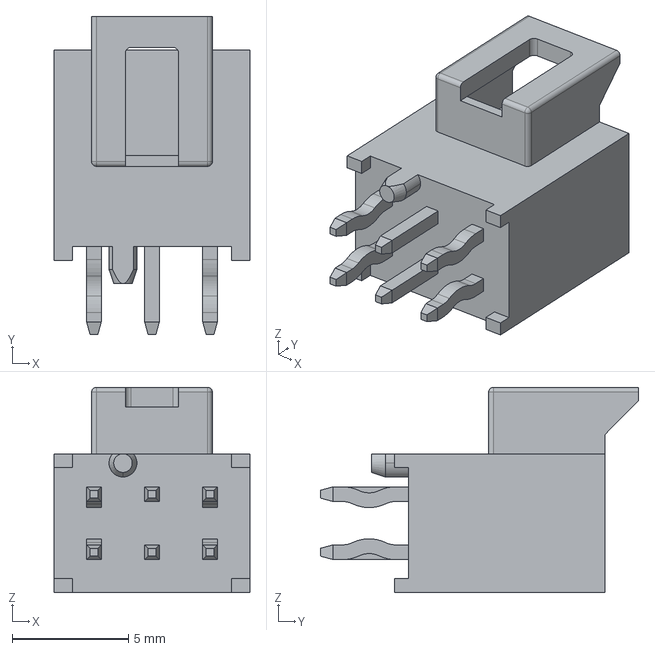
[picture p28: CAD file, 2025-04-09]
Molex.3dmodels/1053101106--3DModel-STEP-510211.STEP
8.44 x 13.7 x 8.84 mm

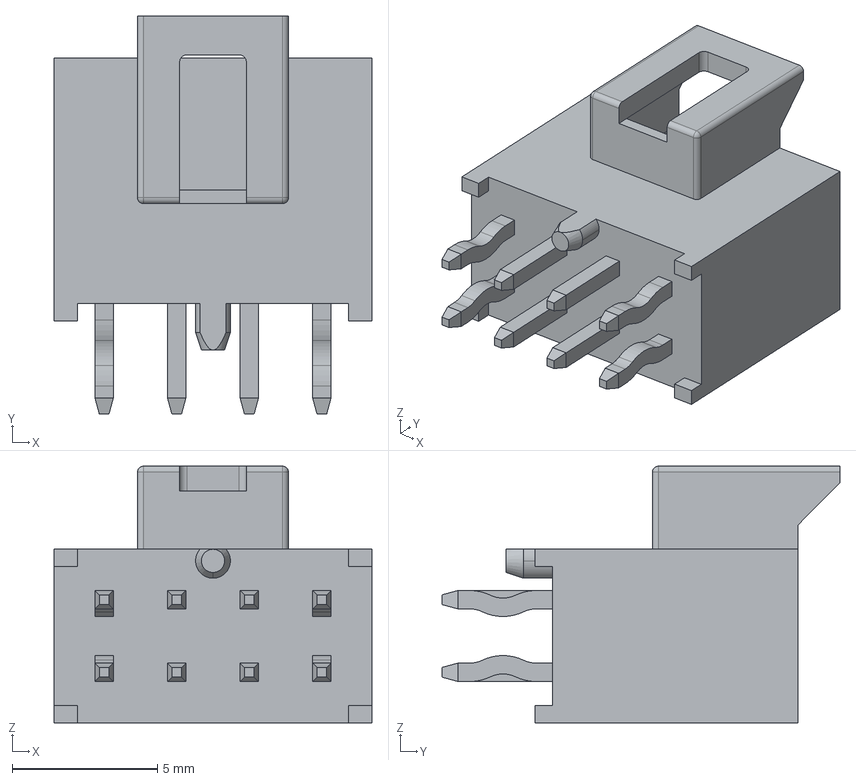
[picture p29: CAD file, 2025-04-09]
Molex.3dmodels/1053101108--3DModel-STEP-510211.STEP
10.9 x 13.7 x 8.84 mm

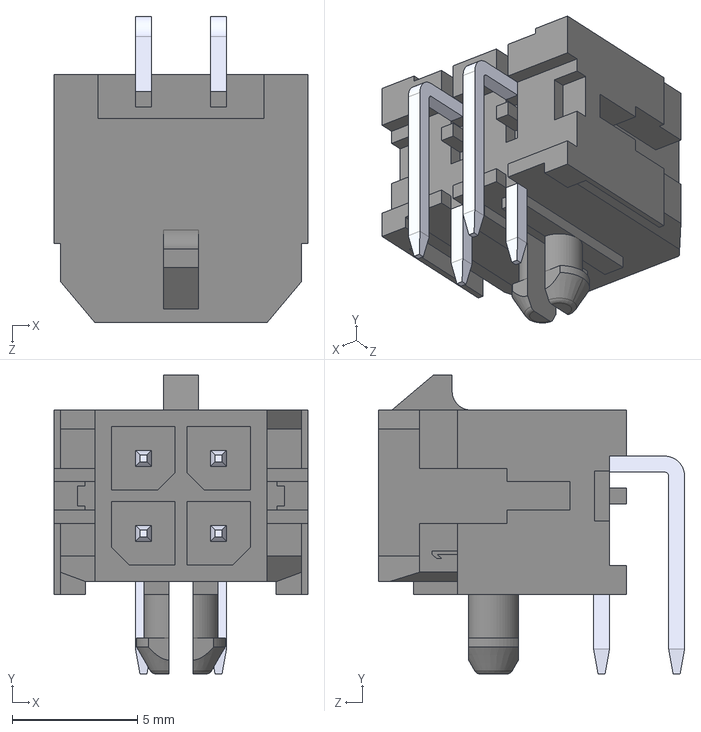
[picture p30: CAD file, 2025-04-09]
Molex.3dmodels/430450400--3DModel-STEP-56544.STEP
10.1 x 12.0 x 12.2 mm

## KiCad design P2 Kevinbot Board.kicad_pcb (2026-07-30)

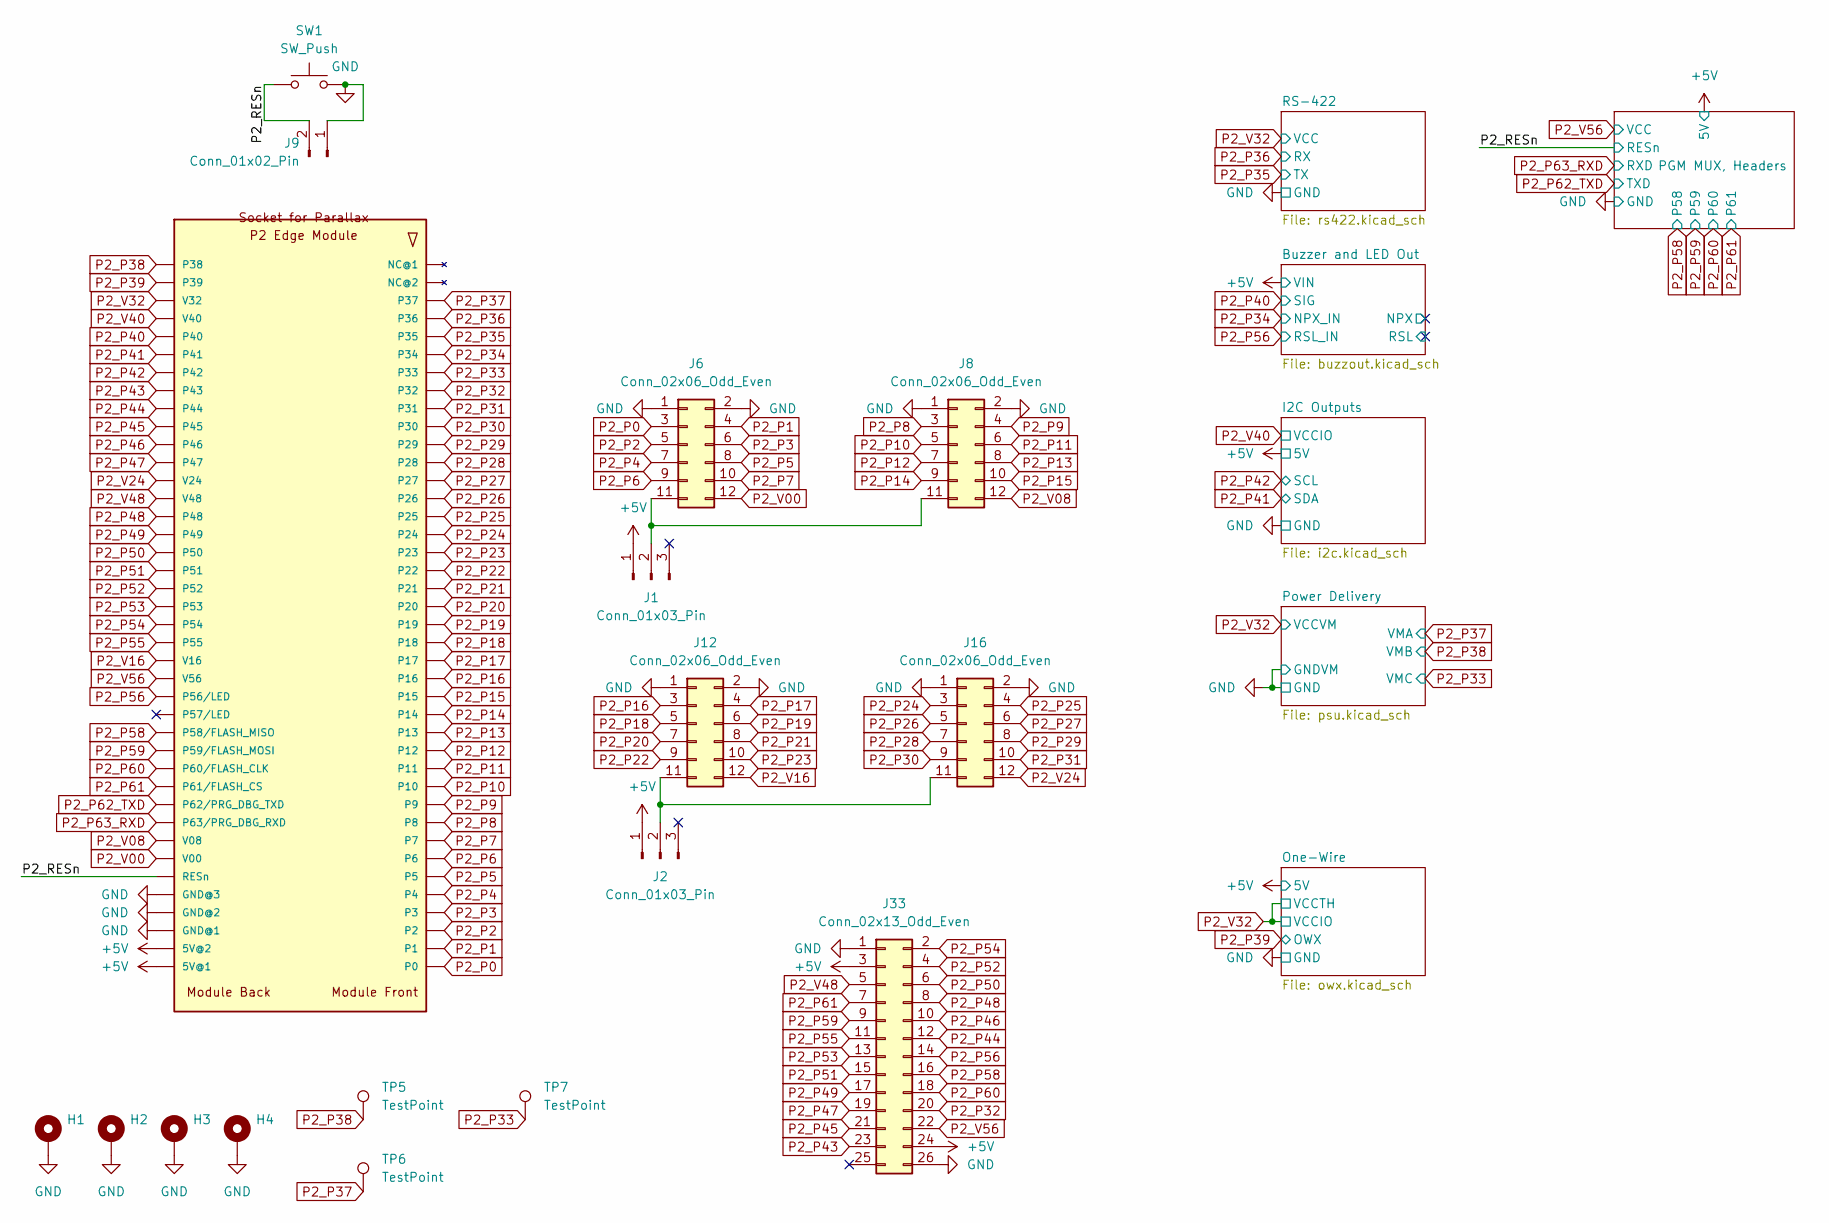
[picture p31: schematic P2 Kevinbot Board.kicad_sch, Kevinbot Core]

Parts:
H1, H2, H3, H4: MountingHole_Pad; MountingHole_3.2mm_M3_Pad
J1, J2: Conn_01x03_Pin; PinHeader_1x03_P2.00mm_Vertical; Part Number 2PH1-03-UA, SPN02SXCN-RC
J6, J8, J12, J16: Conn_02x06_Odd_Even; PinHeader_2x06_P2.54mm_Vertical; Part Number G800W590018EU
J9: Conn_01x02_Pin; Molex_Nano-Fit_105309-xx02_1x02_P2.50mm_Vertical; Part Number 1053091102
J33: Conn_02x13_Odd_Even; PinHeader_2x13_P1.27mm_Vertical; Part Number 3220-26-0100-00
SW1: SW_Push; SW_SPST_PTS645Sx43SMTR92; Part Number PTS645SM43SMTR92 LFS
TP5, TP6, TP7: TestPoint; TestPoint_Pad_D1.0mm
U1: P2_EDGE_MODULE_SOCKET; Card_Edge_TH_RA_1.27mm_80p; Part Number 450-00308

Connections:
+5V: J1.1, J2.1, J33.3, J33.24, U1.41 (5V@1), U1.42 (5V@2); also elsewhere on the board
/P2_RESn: J9.2, SW1.1, U1.46 (RESn); also elsewhere on the board
GND: H1.1, H2.1, H3.1, H4.1, J6.1, J6.2, J8.1, J8.2, J9.1, J12.1, J12.2, J16.1, J16.2, J33.1, J33.26, SW1.2, U1.43 (GND@1), U1.44 (GND@2), U1.45 (GND@3); also elsewhere on the board
unnamed: J1.2, J6.11, J8.11
unnamed: J2.2, J12.11, J16.11
P2_P0: J6.3, U1.40 (P0)
P2_P1: J6.4, U1.39 (P1)
P2_P2: J6.5, U1.38 (P2)
P2_P3: J6.6, U1.37 (P3)
P2_P4: J6.7, U1.36 (P4)
P2_P5: J6.8, U1.35 (P5)
P2_P6: J6.9, U1.34 (P6)
P2_P7: J6.10, U1.33 (P7)
P2_P8: J8.3, U1.32 (P8)
P2_P9: J8.4, U1.31 (P9)
P2_P10: J8.5, U1.30 (P10)
P2_P11: J8.6, U1.29 (P11)
P2_P12: J8.7, U1.28 (P12)
P2_P13: J8.8, U1.27 (P13)
P2_P14: J8.9, U1.26 (P14)
P2_P15: J8.10, U1.25 (P15)
P2_P16: J12.3, U1.24 (P16)
P2_P17: J12.4, U1.23 (P17)
P2_P18: J12.5, U1.22 (P18)
P2_P19: J12.6, U1.21 (P19)
P2_P20: J12.7, U1.20
P2_P21: J12.8, U1.19 (P21)
P2_P22: J12.9, U1.18 (P22)
P2_P23: J12.10, U1.17 (P23)
P2_P24: J16.3, U1.16 (P24)
P2_P25: J16.4, U1.15 (P25)
P2_P26: J16.5, U1.14 (P26)
P2_P27: J16.6, U1.13 (P27)
P2_P28: J16.7, U1.12 (P28)
P2_P29: J16.8, U1.11 (P29)
P2_P30: J16.9, U1.10 (P30)
P2_P31: J16.10, U1.9 (P31)
P2_P32: J33.20, U1.8 (P32)
P2_P33: TP7.1, U1.7 (P33); also elsewhere on the board
P2_P34: U1.6 (P34); also elsewhere on the board
P2_P35: U1.5 (P35); also elsewhere on the board
P2_P36: U1.4 (P36); also elsewhere on the board
P2_P37: TP6.1, U1.3 (P37); also elsewhere on the board
P2_P38: TP5.1, U1.80 (P38); also elsewhere on the board
P2_P39: U1.79 (P39); also elsewhere on the board
P2_P40: U1.76 (P40); also elsewhere on the board
P2_P41: U1.75 (P41); also elsewhere on the board
P2_P42: U1.74 (P42); also elsewhere on the board
P2_P43: J33.23, U1.73 (P43)
P2_P44: J33.12, U1.72 (P44)
P2_P45: J33.21, U1.71 (P45)
P2_P46: J33.10, U1.70 (P46)
P2_P47: J33.19, U1.69 (P47)
P2_P48: J33.8, U1.66 (P48)
P2_P49: J33.17, U1.65 (P49)
P2_P50: J33.6, U1.64 (P50)
P2_P51: J33.15, U1.63 (P51)
P2_P52: J33.4, U1.62 (P52)
P2_P53: J33.13, U1.61 (P53)
P2_P54: J33.2, U1.60 (P54)
P2_P55: J33.11, U1.59 (P55)
P2_P56: J33.14, U1.56 (P56/LED); also elsewhere on the board
P2_P58: J33.16, U1.54 (P58/FLASH_MISO); also elsewhere on the board
P2_P59: J33.9, U1.53 (P59/FLASH_MOSI); also elsewhere on the board
P2_P60: J33.18, U1.52 (P60/FLASH_CLK); also elsewhere on the board
P2_P61: J33.7, U1.51 (P61/FLASH_CS); also elsewhere on the board
P2_P62_TXD: U1.50 (P62/PRG_DBG_TXD); also elsewhere on the board
P2_P63_RXD: U1.49 (P63/PRG_DBG_RXD); also elsewhere on the board
P2_V00: J6.12, U1.47 (V00)
P2_V08: J8.12, U1.48 (V08)
P2_V16: J12.12, U1.58 (V16)
P2_V24: J16.12, U1.68 (V24)
P2_V32: U1.78 (V32); also elsewhere on the board
P2_V40: U1.77 (V40); also elsewhere on the board
P2_V48: J33.5, U1.67 (V48)
P2_V56: J33.22, U1.57 (V56); also elsewhere on the board

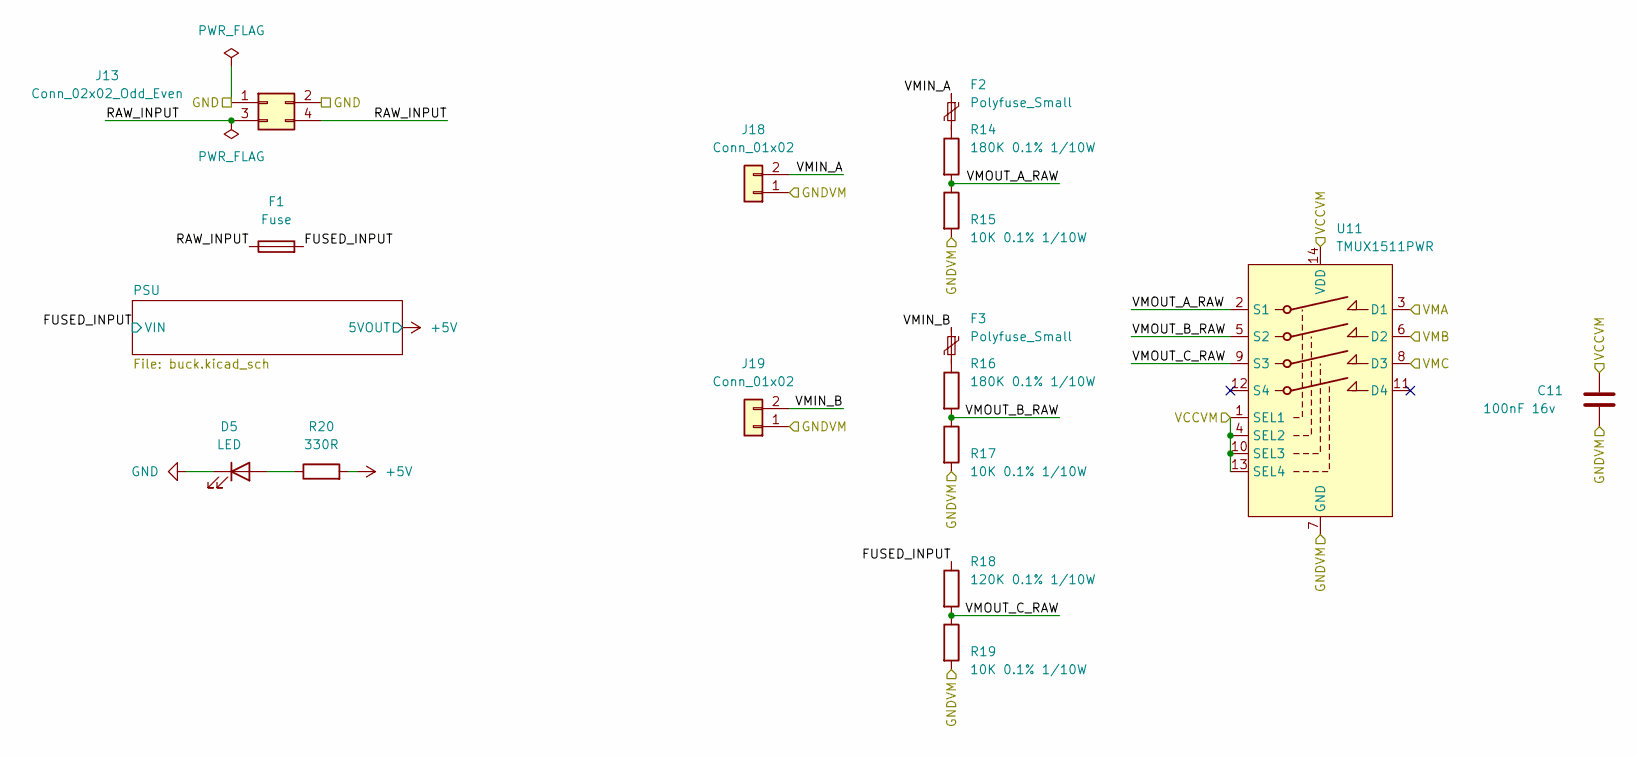
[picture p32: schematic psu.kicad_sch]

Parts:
C11: 100nF 16v; C_0402_1005Metric; Part Number GRM155R71C104KA88D
D5: LED; LED_0603_1608Metric; Part Number 150080SS75000
F1: Fuse; Fuseholder_Blade_Mini_Keystone_3568; Part Number 3568
F2, F3: Polyfuse_Small; Fuse_1206_3216Metric_Pad1.42x1.75mm_HandSolder; Part Number 0ZCJ0005FF2E
J13: Conn_02x02_Odd_Even; Molex_Micro-Fit_3.0_43045-0400_2x02_P3.00mm_Horizontal; Part Number 0430450400
J18, J19: Conn_01x02; Molex_Nano-Fit_105313-xx02_1x02_P2.50mm_Horizontal; Part Number 1053132102
R14, R16: 180K 0.1% 1/10W; R_0603_1608Metric; Part Number RT0603BRD07180KL
R15, R17, R19: 10K 0.1% 1/10W; R_0603_1608Metric; Part Number RT0603BRD0710KL
R18: 120K 0.1% 1/10W; R_0603_1608Metric; Part Number RT0603BRD07120KL
R20: 330R; R_0603_1608Metric; Part Number RC0402FR-07330RL
U11: TMUX1511PWR; TSSOP-14_4.4x5mm_P0.65mm; Part Number TMUX1511PWR

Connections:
+5V: R20.2; also elsewhere on the board
/Power Delivery/FUSED_INPUT: F1.2, R18.1; also elsewhere on the board
/Power Delivery/RAW_INPUT: F1.1, J13.3, J13.4
/Power Delivery/VMIN_A: F2.1, J18.2
/Power Delivery/VMIN_B: F3.1, J19.2
/Power Delivery/VMOUT_A_RAW: R14.2, R15.1, U11.2 (S1)
/Power Delivery/VMOUT_B_RAW: R16.2, R17.1, U11.5 (S2)
/Power Delivery/VMOUT_C_RAW: R18.2, R19.1, U11.9 (S3)
GND: C11.1, D5.1 (K), J13.1, J13.2, J18.1, J19.1, R15.2, R17.2, R19.2, U11.7 (GND); also elsewhere on the board
unnamed: D5.2 (A), R20.1
unnamed: F2.2, R14.1
unnamed: F3.2, R16.1
P2_P33: U11.8 (D3); also elsewhere on the board
P2_P37: U11.3 (D1); also elsewhere on the board
P2_P38: U11.6 (D2); also elsewhere on the board
P2_V32: C11.2, U11.1 (SEL1), U11.4 (SEL2), U11.10 (SEL3), U11.13 (SEL4), U11.14 (VDD); also elsewhere on the board

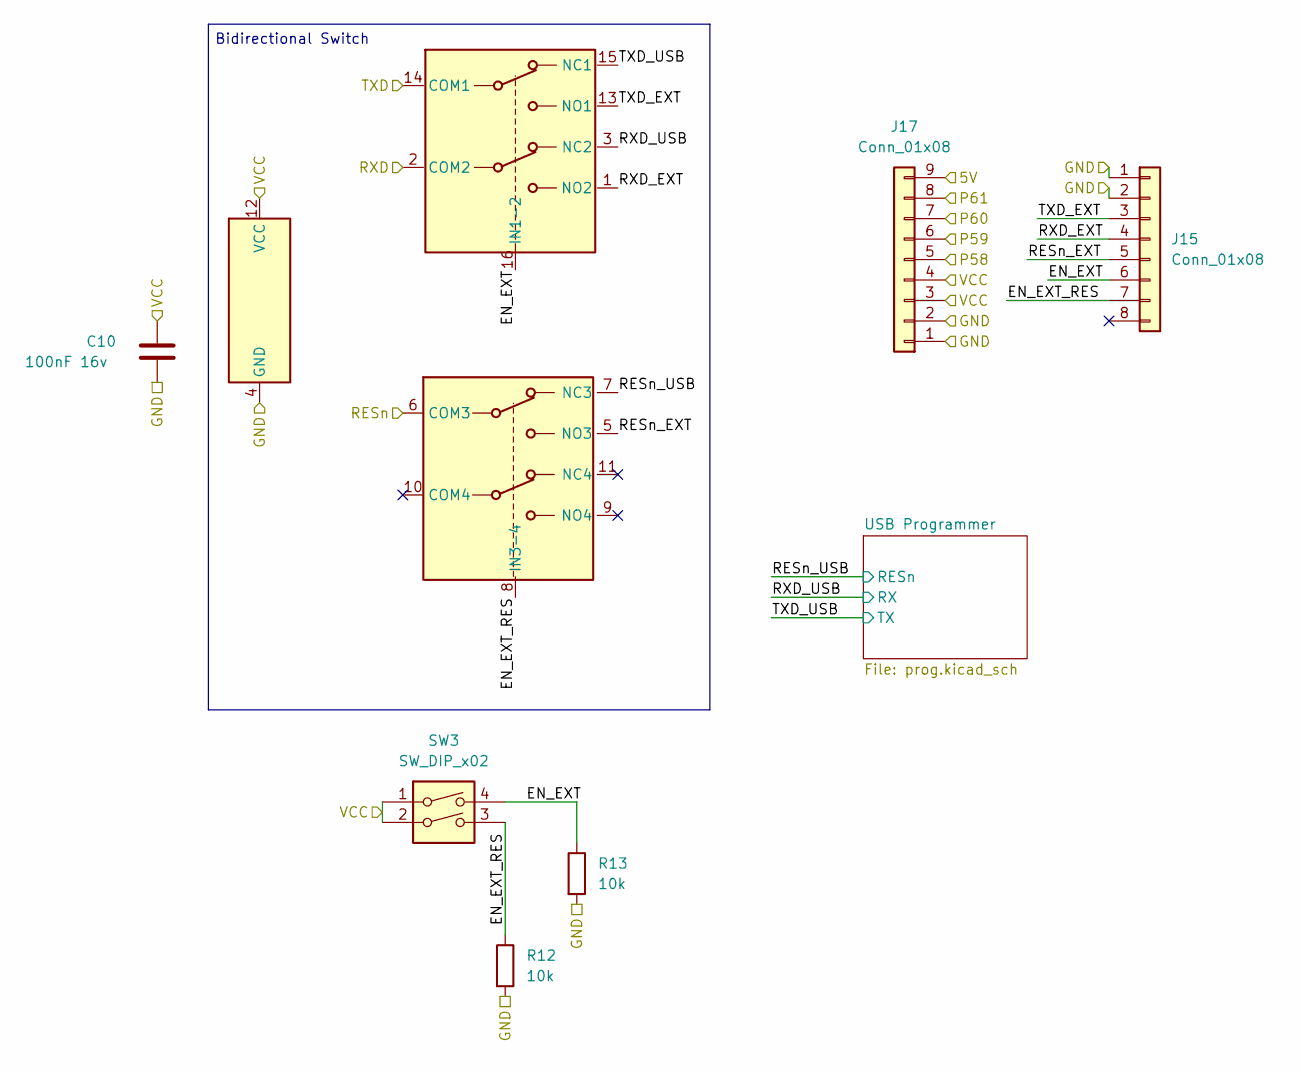
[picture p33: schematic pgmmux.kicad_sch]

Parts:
C10: 100nF 16v; C_0402_1005Metric; Part Number GRM155R71C104KA88D
J15: Conn_01x08; PinSocket_1x08_P2.54mm_Vertical; Part Number PPTC081LFBN-RC
J17: Conn_01x08; PinSocket_1x09_P2.54mm_Vertical; Part Number PPTC091LFBN-RC
R12, R13: 10k; R_0402_1005Metric; Part Number RC0402FR-0710KL
SW3: SW_DIP_x02; SW_DIP_SPSTx02_Slide_Copal_CHS-02A_W5.08mm_P1.27mm_JPin; Part Number CHS-02TA
U10: TS3A44159PWR; TSSOP-16_4.4x5mm_P0.65mm; Part Number TS3A44159PWR

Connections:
+5V: J17.9; also elsewhere on the board
/P2_RESn: U10.6 (COM3); also elsewhere on the board
/PGM MUX, Headers/EN_EXT: J15.6, R13.1, SW3.4, U10.16 (IN1-2)
/PGM MUX, Headers/EN_EXT_RES: J15.7, R12.1, SW3.3, U10.8 (IN3-4)
/PGM MUX, Headers/RESn_EXT: J15.5, U10.5 (NO3)
/PGM MUX, Headers/RESn_USB: U10.7 (NC3); also elsewhere on the board
/PGM MUX, Headers/RXD_EXT: J15.4, U10.1 (NO2)
/PGM MUX, Headers/RXD_USB: U10.3 (NC2); also elsewhere on the board
/PGM MUX, Headers/TXD_EXT: J15.3, U10.13 (NO1)
/PGM MUX, Headers/TXD_USB: U10.15 (NC1); also elsewhere on the board
GND: C10.1, J15.1, J15.2, J17.1, J17.2, R12.2, R13.2, U10.4 (GND); also elsewhere on the board
P2_P58: J17.5; also elsewhere on the board
P2_P59: J17.6; also elsewhere on the board
P2_P60: J17.7; also elsewhere on the board
P2_P61: J17.8; also elsewhere on the board
P2_P62_TXD: U10.14 (COM1); also elsewhere on the board
P2_P63_RXD: U10.2 (COM2); also elsewhere on the board
P2_V56: C10.2, J17.3, J17.4, SW3.1, SW3.2, U10.12 (VCC); also elsewhere on the board

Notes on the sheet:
Bidirectional Switch

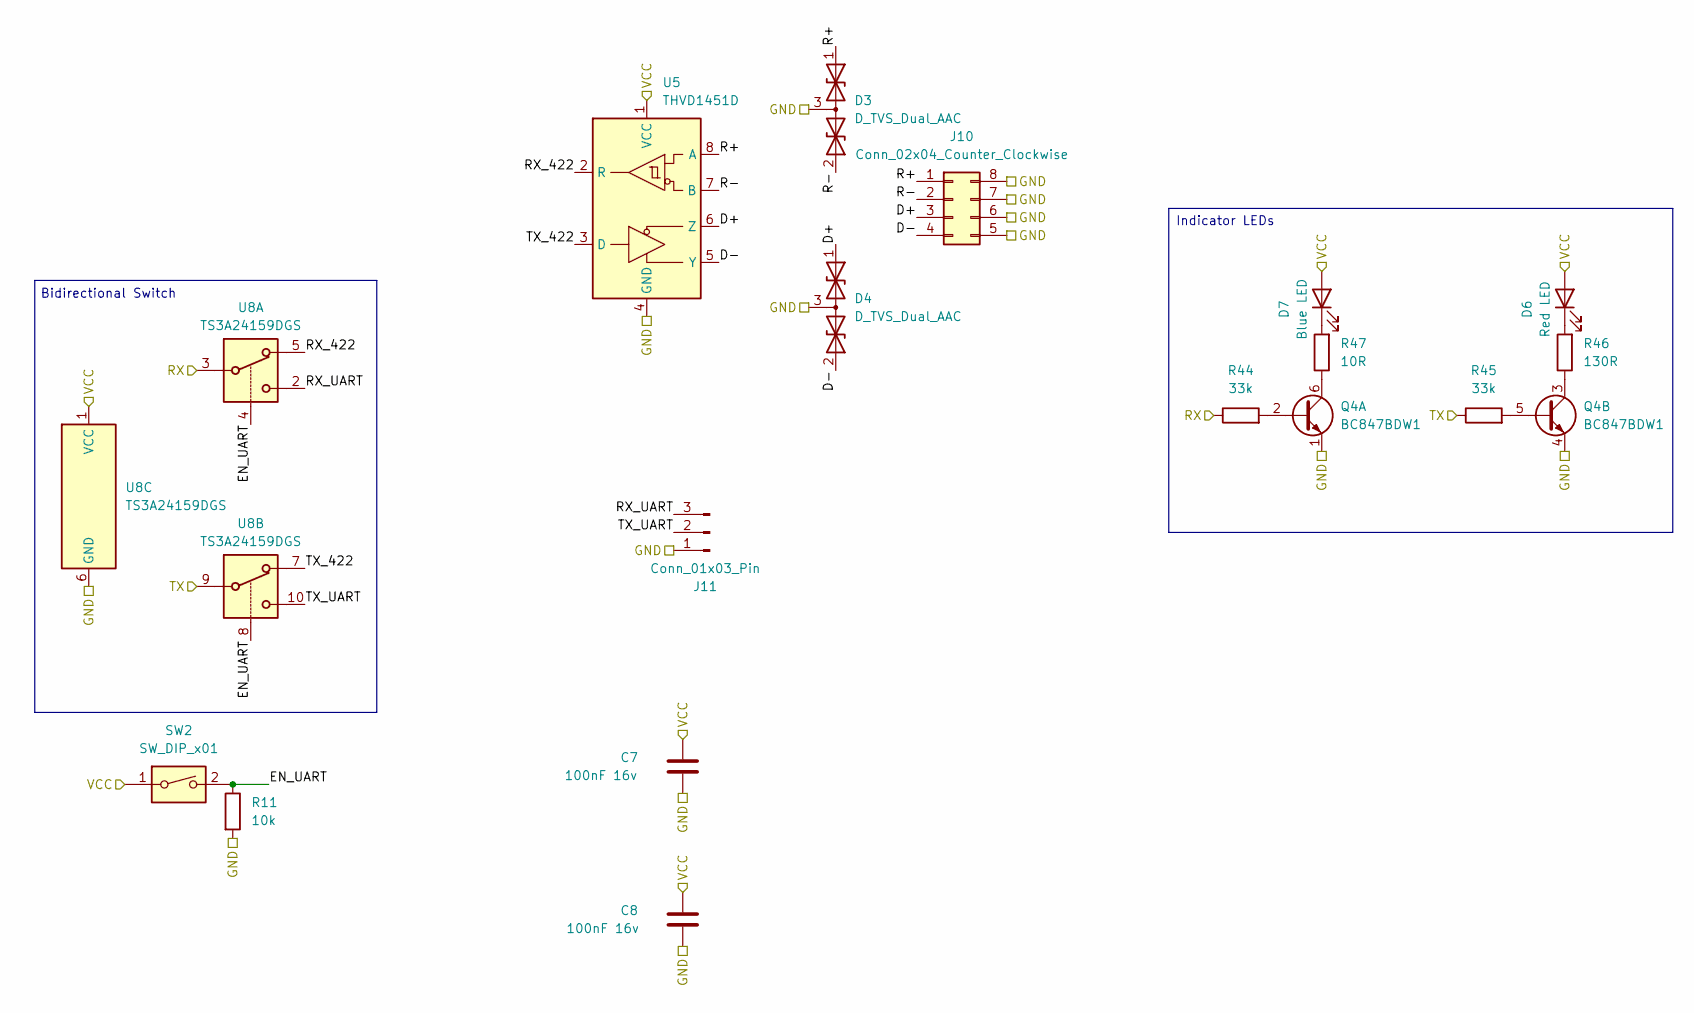
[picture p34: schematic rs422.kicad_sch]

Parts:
C7, C8: 100nF 16v; C_0402_1005Metric; Part Number GRM155R71C104KA88D
D3, D4: D_TVS_Dual_AAC; SOT-23; Part Number D5V0L2B3SO-7
D6: Red LED; LED_0603_1608Metric; Part Number 150060RS75000
D7: Blue LED; LED_0603_1608Metric; Part Number 150060BS75000
J10: Conn_02x04_Counter_Clockwise; Molex_Nano-Fit_105310-xx08_2x04_P2.50mm_Vertical; Part Number 1053101108
J11: Conn_01x03_Pin; JST_PH_B3B-PH-K_1x03_P2.00mm_Vertical; Part Number B3B-PH-K-S
Q4: BC847BDW1; SOT-363_SC-70-6; Part Number BC847BDW1T1G
R11: 10k; R_0402_1005Metric; Part Number RC0402FR-0710KL
R44, R45: 33k; R_0402_1005Metric; Part Number RC0402FR-0733KL
R46: 130R; R_0402_1005Metric; Part Number RC0402FR-07130RL
R47: 10R; R_0402_1005Metric; Part Number RC0402FR-0710RL
SW2: SW_DIP_x01; SW_DIP_SPSTx01_Slide_Copal_CHS-01A_W5.08mm_P1.27mm_JPin; Part Number CHS-01A
U5: THVD1451D; SOIC-8_3.9x4.9mm_P1.27mm; Part Number THVD1451D
U8: TS3A24159DGS; TSSOP-10_3x3mm_P0.5mm; Part Number TS3A24159DGSR

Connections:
/RS-422/D+: D4.1 (A1), J10.3, U5.6 (Z)
/RS-422/D-: D4.2 (A2), J10.4, U5.5 (Y)
/RS-422/EN_UART: R11.1, SW2.2, U8.4, U8.8
/RS-422/R+: D3.1 (A1), J10.1, U5.8 (A)
/RS-422/R-: D3.2 (A2), J10.2, U5.7 (B)
/RS-422/RX_422: U5.2 (R), U8.5
/RS-422/RX_UART: J11.3, U8.2
/RS-422/TX_422: U5.3 (D), U8.7
/RS-422/TX_UART: J11.2, U8.10
GND: C7.1, C8.1, D3.3 (common), D4.3 (common), J10.5, J10.6, J10.7, J10.8, J11.1, Q4.1 (E1), Q4.4 (E2), R11.2, U5.4 (GND), U8.6 (GND); also elsewhere on the board
unnamed: D6.1 (K), R46.2
unnamed: D7.1 (K), R47.2
unnamed: Q4.2 (B1), R44.2
unnamed: Q4.6 (C1), R47.1
unnamed: Q4.5 (B2), R45.2
unnamed: Q4.3 (C2), R46.1
P2_P35: R45.1, U8.9; also elsewhere on the board
P2_P36: R44.1, U8.3; also elsewhere on the board
P2_V32: C7.2, C8.2, D6.2 (A), D7.2 (A), SW2.1, U5.1 (VCC), U8.1 (VCC); also elsewhere on the board

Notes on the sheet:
Bidirectional Switch
Indicator LEDs

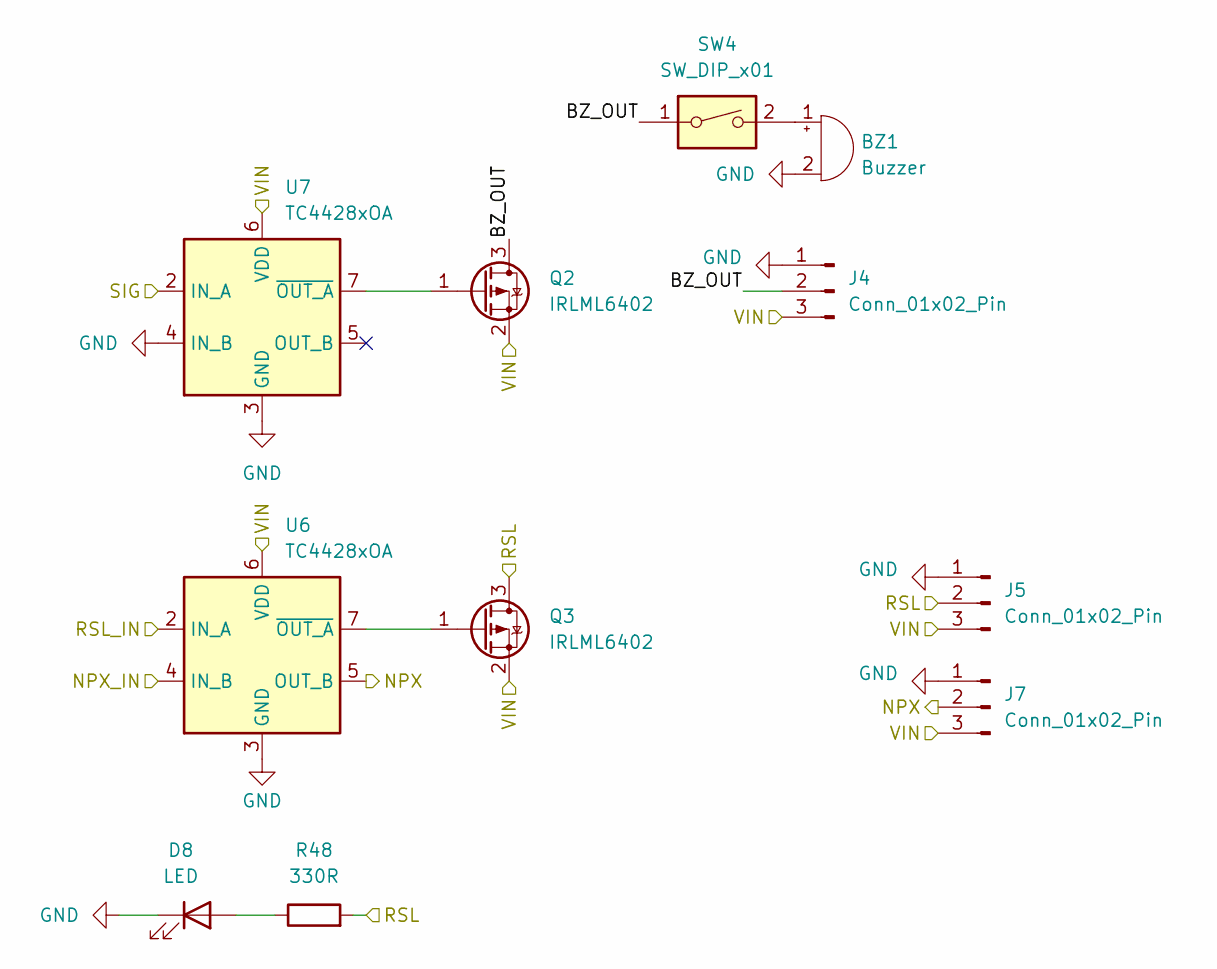
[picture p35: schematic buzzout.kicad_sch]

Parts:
BZ1: Buzzer; Buzzer_TDK_PS1240P02BT_D12.2mm_H6.5mm; Part Number PS1240P02BT
D8: LED; LED_0603_1608Metric; Part Number 150060YS75000
J4, J5, J7: Conn_01x02_Pin; Molex_Nano-Fit_105309-xx03_1x03_P2.50mm_Vertical; Part Number 1053091103
Q2, Q3: IRLML6402; SOT-23; Part Number IRLML6402TRPBF
R48: 330R; R_0603_1608Metric; Part Number RC0402FR-07330RL
SW4: SW_DIP_x01; SW_DIP_SPSTx01_Slide_Copal_CHS-01A_W5.08mm_P1.27mm_JPin; Part Number CHS-01A
U6, U7: TC4428xOA; SOIC-8_3.9x4.9mm_P1.27mm; Part Number TC4428EOA713

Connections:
+5V: J4.3, J5.3, J7.3, Q2.2 (S), Q3.2 (S), U6.6 (VDD), U7.6 (VDD); also elsewhere on the board
/Buzzer and LED Out/BZ_OUT: J4.2, Q2.3 (D), SW4.1
/Buzzer and LED Out/NPX: J7.2, U6.5 (OUT_B)
/Buzzer and LED Out/RSL: J5.2, Q3.3 (D), R48.2
GND: BZ1.2 (-), D8.1 (K), J4.1, J5.1, J7.1, U6.3 (GND), U7.3 (GND), U7.4 (IN_B); also elsewhere on the board
unnamed: BZ1.1 (+), SW4.2
unnamed: D8.2 (A), R48.1
unnamed: Q2.1 (G), U7.7 (~OUT_A)
unnamed: Q3.1 (G), U6.7 (~OUT_A)
P2_P34: U6.4 (IN_B); also elsewhere on the board
P2_P40: U7.2 (IN_A); also elsewhere on the board
P2_P56: U6.2 (IN_A); also elsewhere on the board

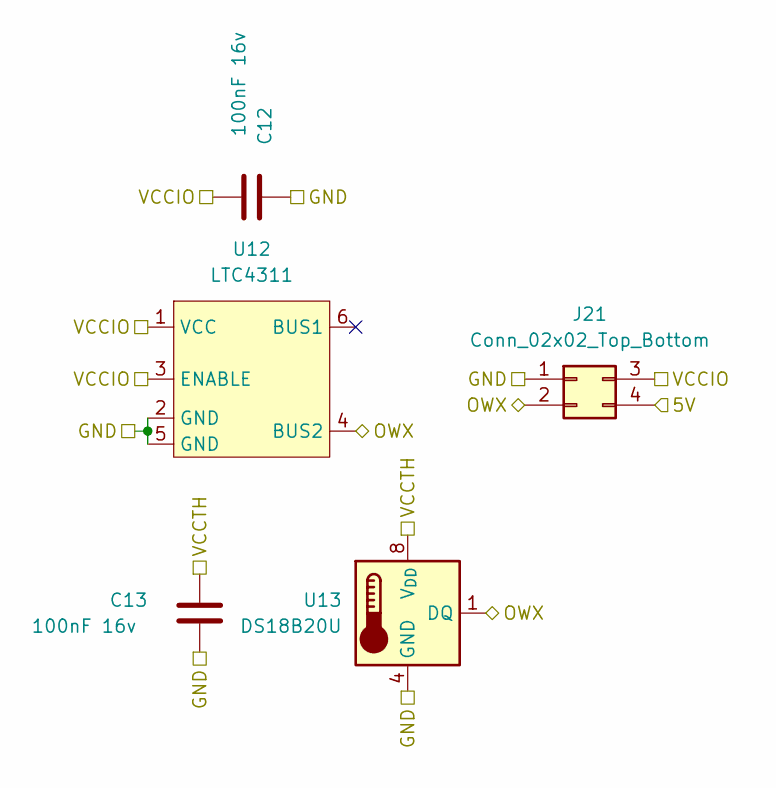
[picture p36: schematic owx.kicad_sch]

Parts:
C12, C13: 100nF 16v; C_0402_1005Metric; Part Number GRM155R71C104KA88D
J21: Conn_02x02_Top_Bottom; Molex_Nano-Fit_105310-xx04_2x02_P2.50mm_Vertical; Part Number 1053101104
U12: LTC4311; SOT-363_SC-70-6; Part Number LTC4311CSC6#TRPBF
U13: DS18B20U; MSOP-8_3x3mm_P0.65mm; Part Number DS18B20U+T&R

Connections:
+5V: J21.4; also elsewhere on the board
GND: C12.2, C13.1, J21.1, U12.2 (GND), U12.5 (GND), U13.4 (GND); also elsewhere on the board
P2_P39: J21.2, U12.4 (BUS2), U13.1 (DQ); also elsewhere on the board
P2_V32: C12.1, C13.2, J21.3, U12.1 (VCC), U12.3 (ENABLE), U13.8 (V_{DD}); also elsewhere on the board

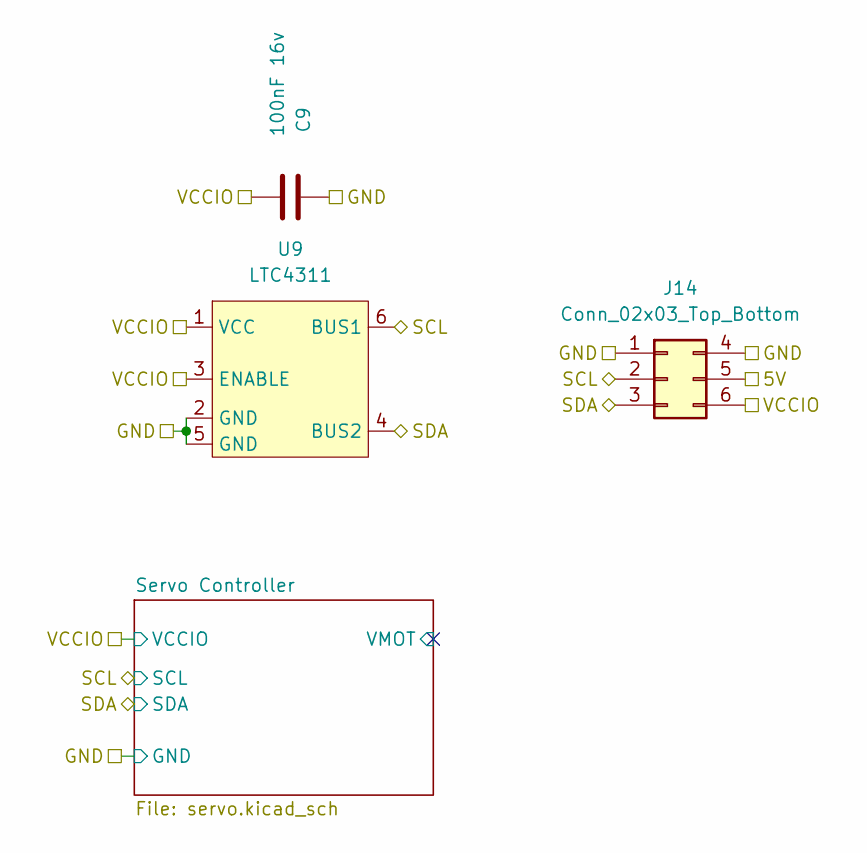
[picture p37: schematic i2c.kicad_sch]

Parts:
C9: 100nF 16v; C_0402_1005Metric; Part Number GRM155R71C104KA88D
J14: Conn_02x03_Top_Bottom; Molex_Nano-Fit_105310-xx06_2x03_P2.50mm_Vertical; Part Number 1053101106
U9: LTC4311; SOT-363_SC-70-6; Part Number LTC4311CSC6#TRPBF

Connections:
+5V: J14.5; also elsewhere on the board
GND: C9.2, J14.1, J14.4, U9.2 (GND), U9.5 (GND); also elsewhere on the board
P2_P41: J14.3, U9.4 (BUS2); also elsewhere on the board
P2_P42: J14.2, U9.6 (BUS1); also elsewhere on the board
P2_V40: C9.1, J14.6, U9.1 (VCC), U9.3 (ENABLE); also elsewhere on the board

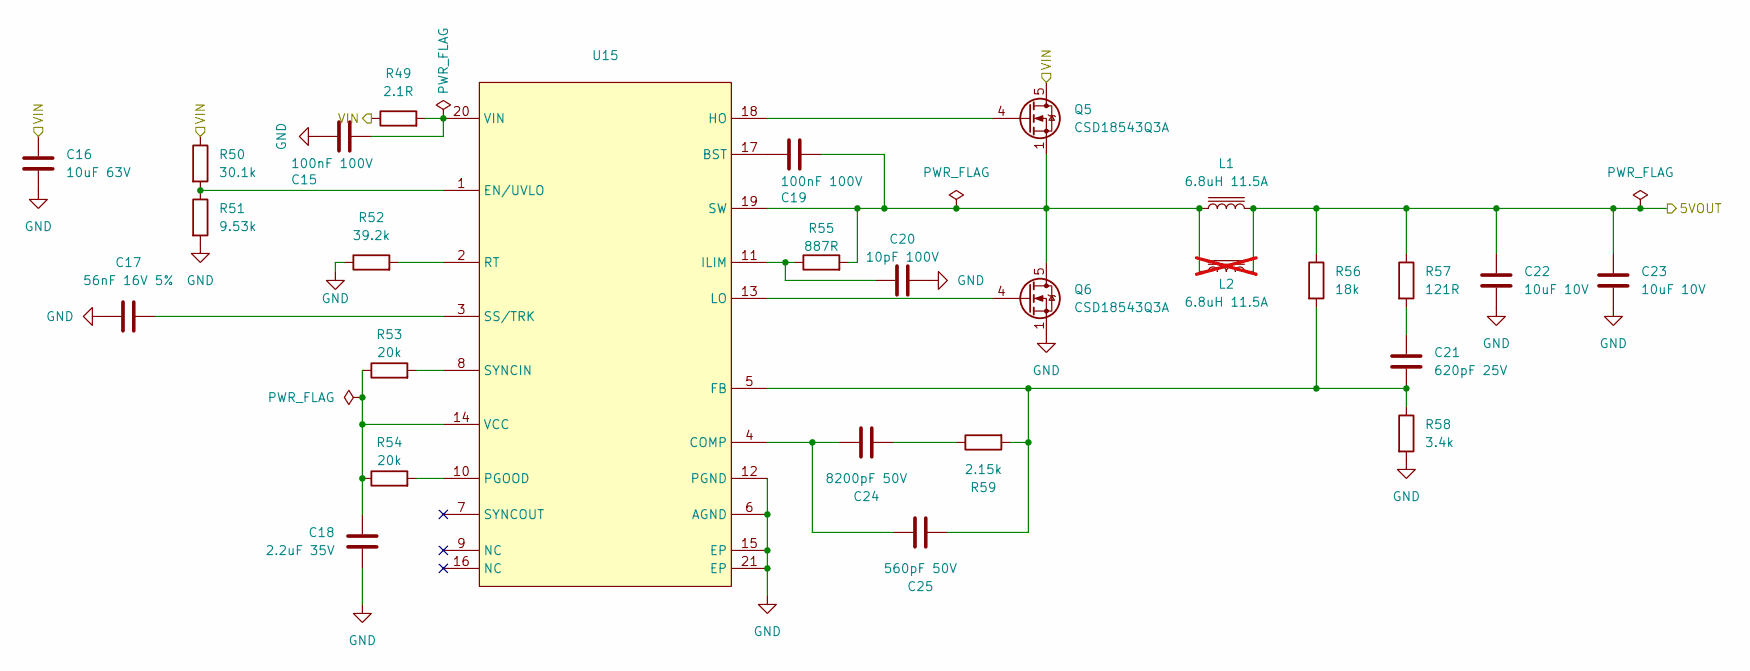
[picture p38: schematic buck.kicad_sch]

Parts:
C15, C19: 100nF 100V; C_0603_1608Metric; Part Number C1608X7S2A104K080AB
C16: 10uF 63V; C_1210_3225Metric; Part Number CL32B106KMVNNWE
C17: 56nF 16V 5%; C_0603_1608Metric; Part Number C0603C563J4RACTU
C18: 2.2uF 35V; C_0603_1608Metric; Part Number C1608X5R1V225K080AC
C20: 10pF 100V; C_0603_1608Metric; Part Number GCM1885C2A100JA16D
C21: 620pF 25V; C_0603_1608Metric; Part Number C0603C621J3GACTU
C22, C23: 10uF 10V; C_1210_3225Metric; Part Number C1210C106K8PACTU
C24: 8200pF 50V; C_0603_1608Metric; Part Number GCM1885C1H822JA16D
C25: 560pF 50V; C_0603_1608Metric; Part Number C0603C561J5GACTU
L1: 6.8uH 11.5A; L_Bourns_SRP1245A; Part Number SRP1265A-6R8M
L2: 6.8uH 11.5A; L_Coilcraft_XAL7070-XXX-NOSILK; Part Number XAL7070-682MEC; not fitted
Q5, Q6: CSD18543Q3A; VSON-8_3.3x3.3mm_P0.65mm_NexFET; Part Number CSD18543Q3A
R49: 2.1R; R_0603_1608Metric; Part Number CRCW06032R10FKEA
R50: 30.1k; R_0603_1608Metric; Part Number RC0603FR-0730K1L
R51: 9.53k; R_0603_1608Metric; Part Number RC0603FR-079K53L
R52: 39.2k; R_0603_1608Metric; Part Number RC0603FR-0739K2L
R53, R54: 20k; R_0603_1608Metric; Part Number CRCW060320K0FKEA
R55: 887R; R_0603_1608Metric; Part Number RC0603FR-07887RL
R56: 18k; R_0603_1608Metric; Part Number RC0603FR-0718KL
R57: 121R; R_0603_1608Metric; Part Number RC0603FR-07121RL
R58: 3.4k; R_0603_1608Metric; Part Number RC0603FR-073K4L
R59: 2.15k; R_0603_1608Metric; Part Number RC0603FR-072K15L
U15: Texas_RGY_R-PVQFN-N20_EP2.05x3.05mm_ThermalVias; Part Number LM25145RGYR

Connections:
+5V: C22.1, C23.1, L1.2, L2.2, R56.1, R57.1; also elsewhere on the board
/Power Delivery/FUSED_INPUT: C16.1, Q5.5 (D), R49.1, R50.1; also elsewhere on the board
GND: C15.2, C16.2, C17.2, C18.2, C20.2, C22.2, C23.2, Q6.1 (S), Q6.2 (S), Q6.3 (S), R51.2, R52.1, R58.2, U15.6 (AGND), U15.12 (PGND), U15.15 (EP), U15.21 (EP); also elsewhere on the board
unnamed: C21.1, R57.2
unnamed: C24.2, R59.1
unnamed: Q5.4 (G), U15.18 (HO)
unnamed: C19.1, L1.1, L2.1, Q5.1 (S), Q5.2 (S), Q5.3 (S), Q6.5 (D), R55.2, U15.19 (SW)
unnamed: Q6.4 (G), U15.13 (LO)
unnamed: C19.2, U15.17 (BST)
unnamed: C24.1, C25.1, U15.4 (COMP)
unnamed: R50.2, R51.1, U15.1 (EN/UVLO)
unnamed: C21.2, C25.2, R56.2, R58.1, R59.2, U15.5 (FB)
unnamed: C20.1, R55.1, U15.11 (ILIM)
unnamed: R54.2, U15.10 (PGOOD)
unnamed: R52.2, U15.2 (RT)
unnamed: C17.1, U15.3 (SS/TRK)
unnamed: R53.2, U15.8 (SYNCIN)
unnamed: C18.1, R53.1, R54.1, U15.14 (VCC)
unnamed: C15.1, R49.2, U15.20 (VIN)

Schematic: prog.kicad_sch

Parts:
C1, C5: 10nF 16v; C_0402_1005Metric; Part Number GRM155R71C103KA01D
C2, C3: 4.7uF 10v; C_0402_1005Metric; Part Number GRM155R61A475MEAAD
C4, C6: 100nF 16v; C_0402_1005Metric; Part Number GRM155R71C104KA88D
D1: Red LED; LED_0603_1608Metric; Part Number 150060RS75000
D2: Blue LED; LED_0603_1608Metric; Part Number 150060BS75000
FB1: 220R; L_0603_1608Metric; Part Number MPZ1608S221ATA00
J3: USB_C_Receptacle_USB2.0_16P; USB_C_Receptacle_GCT_USB4105-xx-A_16P_TopMnt_Horizontal; Part Number USB4105-GF-A
Q1: MUN5211T1G; SOT-323_SC-70; Part Number MUN5211T1G
R1, R2: 5.1k; R_0402_1005Metric; Part Number RC0402FR-075K1L
R3, R4: 27R; R_0402_1005Metric; Part Number RC0402FR-0727RL
R5, R6: 240R; R_0402_1005Metric; Part Number RC0402FR-07240RL
R7: 470k; R_0402_1005Metric; Part Number RC0402FR-07470KL
R8, R9, R10: 100k; R_0402_1005Metric; Part Number RC0402FR-07100KL
TP1, TP2, TP3, TP4: TestPoint; TestPoint_Pad_D1.0mm
U2: FT231XS; SSOP-20_3.9x8.7mm_P0.635mm; Part Number FT231XS-R
U3, U4: 74LVC1G126; SOT-353_SC-70-5; Part Number 74LVC1G126SE-7

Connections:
+5VUSB: C2.1, C3.1, FB1.2, R5.2, U2.15 (VCC)
/PGM MUX, Headers/RESn_USB: Q1.3 (C); also elsewhere on the board
/PGM MUX, Headers/RXD_USB: R6.1, R7.1; also elsewhere on the board
/PGM MUX, Headers/TXD_USB: R10.1, U4.4; also elsewhere on the board
/PGM MUX, Headers/USB Programmer/DTR: C5.1, U2.1 (~DTR)
/PGM MUX, Headers/USB Programmer/FT_RX: U2.4 (RXD), U3.4
/PGM MUX, Headers/USB Programmer/FT_TX: U2.20 (TXD), U4.2
/PGM MUX, Headers/USB Programmer/SLEEP: R8.2, TP1.1, U2.17 (CBUS1), U3.1
/PGM MUX, Headers/USB Programmer/TXDEN: R9.2, TP2.1, U2.10 (CBUS2), U4.1
/PGM MUX, Headers/USB Programmer/VCCIO: C4.2, C6.2, R10.2, U2.3 (VCCIO), U2.13 (3V3OUT), U2.14 (~RESET), U3.5 (VCC), U4.5 (VCC)
GND: C1.2, C2.2, C3.2, C4.1, C6.1, J3.A1 (GND), J3.A12 (GND), J3.B1 (GND), J3.B12 (GND), J3.S1 (SHIELD), Q1.2 (E), R1.1, R2.1, R7.2, R8.1, R9.1, U2.6 (GND), U2.16 (GND), U3.3 (GND), U4.3 (GND); also elsewhere on the board
unnamed: D1.2 (A), D2.2 (A), R5.1
unnamed: D1.1 (K), TP3.1, U2.18 (CBUS0)
unnamed: D2.1 (K), TP4.1, U2.19 (CBUS3)
unnamed: J3.A5 (CC1), R2.2
unnamed: J3.B5 (CC2), R1.2
unnamed: J3.A6 (D+), J3.B6 (D+), R4.1
unnamed: J3.A7 (D-), J3.B7 (D-), R3.1
unnamed: C5.2, Q1.1 (B)
unnamed: R6.2, U3.2
unnamed: R3.2, U2.12 (USBDM)
unnamed: R4.2, U2.11 (USBDP)
VBUS: C1.1, FB1.1, J3.A4 (VBUS), J3.A9 (VBUS), J3.B4 (VBUS), J3.B9 (VBUS)

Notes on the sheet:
RX tri-state
TX tri-state
~20uS reset pulse
idle high

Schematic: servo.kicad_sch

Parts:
C14: 100nF 16v; C_0402_1005Metric; Part Number GRM155R71C104KA88D
C26: 1500uf; CP_Radial_D8.0mm_P3.50mm; Part Number A750KS158M0JAAE014
F4: Fuse; Fuseholder_Blade_Mini_Keystone_3568; Part Number 3568
J20, J22, J23, J24: Conn_04x03_Servo; ServoHeader_03x04_P2.54_Vertical
J25: Conn_02x02_Odd_Even; Molex_Micro-Fit_3.0_43045-0400_2x02_P3.00mm_Horizontal; Part Number 0430450400
R21, R22, R23, R24, R25, R26, R27: 10k; R_0402_1005Metric; Part Number RC0402FR-0710KL
R28, R29, R30, R31, R32, R33, R34, R35, R36, R37, R38, R39, R40, R41, R42, R43: 220R; R_0402_1005Metric; Part Number RC0402FR-07220RL
U14: PCA9685BS; QFN-28-1EP_6x6mm_P0.65mm_EP4.25x4.25mm; Part Number PCA9685BS,118

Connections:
/I2C Outputs/Servo Controller/S0: R40.1, U14.3 (LED0)
/I2C Outputs/Servo Controller/S1: R32.1, U14.4 (LED1)
/I2C Outputs/Servo Controller/S2: R41.1, U14.5 (LED2)
/I2C Outputs/Servo Controller/S3: R33.1, U14.6 (LED3)
/I2C Outputs/Servo Controller/S4: R42.1, U14.7 (LED4)
/I2C Outputs/Servo Controller/S5: R34.1, U14.8 (LED5)
/I2C Outputs/Servo Controller/S6: R43.1, U14.9 (LED6)
/I2C Outputs/Servo Controller/S7: R35.1, U14.10 (LED7)
/I2C Outputs/Servo Controller/S8: R36.1, U14.12 (LED8)
/I2C Outputs/Servo Controller/S9: R28.1, U14.13 (LED9)
/I2C Outputs/Servo Controller/S10: R37.1, U14.14 (LED10)
/I2C Outputs/Servo Controller/S11: R29.1, U14.15 (LED11)
/I2C Outputs/Servo Controller/S12: R38.1, U14.16 (LED12)
/I2C Outputs/Servo Controller/S13: R30.1, U14.17 (LED13)
/I2C Outputs/Servo Controller/S14: R39.1, U14.18 (LED14)
/I2C Outputs/Servo Controller/S15: R31.1, U14.19 (LED15)
/I2C Outputs/Servo Controller/VMOT: C26.1, F4.1, J20.2 (VIN), J22.2 (VIN), J23.2 (VIN), J24.2 (VIN)
GND: C14.1, C26.2, J20.1 (GND), J22.1 (GND), J23.1 (GND), J24.1 (GND), J25.1, J25.2, R21.1, R22.1, R23.1, R24.1, R25.1, R26.1, R27.1, U14.11 (VSS), U14.22 (EXTCLK), U14.29 (VSS); also elsewhere on the board
unnamed: J20.3 (S1), R28.2
unnamed: J20.4 (S2), R29.2
unnamed: J20.5 (S3), R30.2
unnamed: J20.6 (S4), R31.2
unnamed: J22.3 (S1), R32.2
unnamed: J22.4 (S2), R33.2
unnamed: J22.5 (S3), R34.2
unnamed: J22.6 (S4), R35.2
unnamed: J23.3 (S1), R36.2
unnamed: J23.4 (S2), R37.2
unnamed: J23.5 (S3), R38.2
unnamed: J23.6 (S4), R39.2
unnamed: J24.3 (S1), R40.2
unnamed: J24.4 (S2), R41.2
unnamed: J24.5 (S3), R42.2
unnamed: J24.6 (S4), R43.2
unnamed: F4.2, J25.3, J25.4
unnamed: R22.2, U14.26 (A0)
unnamed: R23.2, U14.27 (A1)
unnamed: R24.2, U14.28 (A2)
unnamed: R25.2, U14.1 (A3)
unnamed: R26.2, U14.2 (A4)
unnamed: R27.2, U14.21 (A5)
unnamed: R21.2, U14.20 (~OE)
P2_P41: U14.24 (SDA); also elsewhere on the board
P2_P42: U14.23 (SCL); also elsewhere on the board
P2_V40: C14.2, U14.25 (VDD); also elsewhere on the board

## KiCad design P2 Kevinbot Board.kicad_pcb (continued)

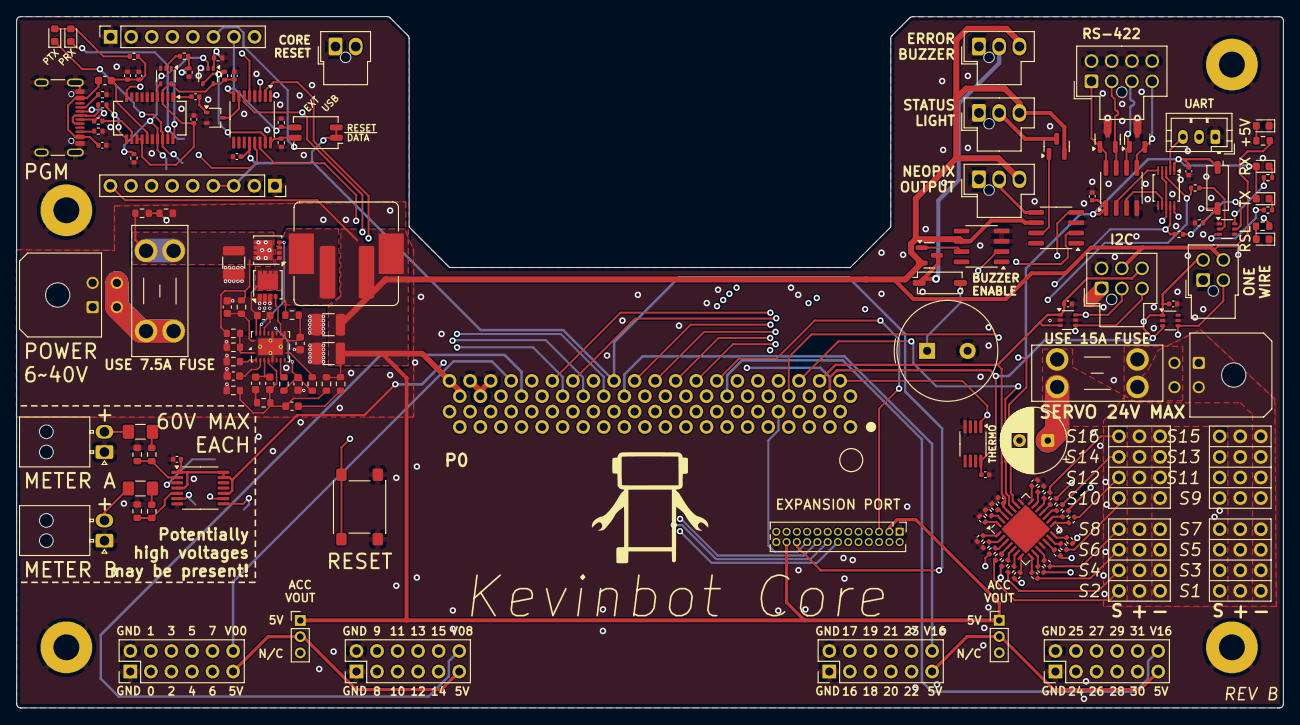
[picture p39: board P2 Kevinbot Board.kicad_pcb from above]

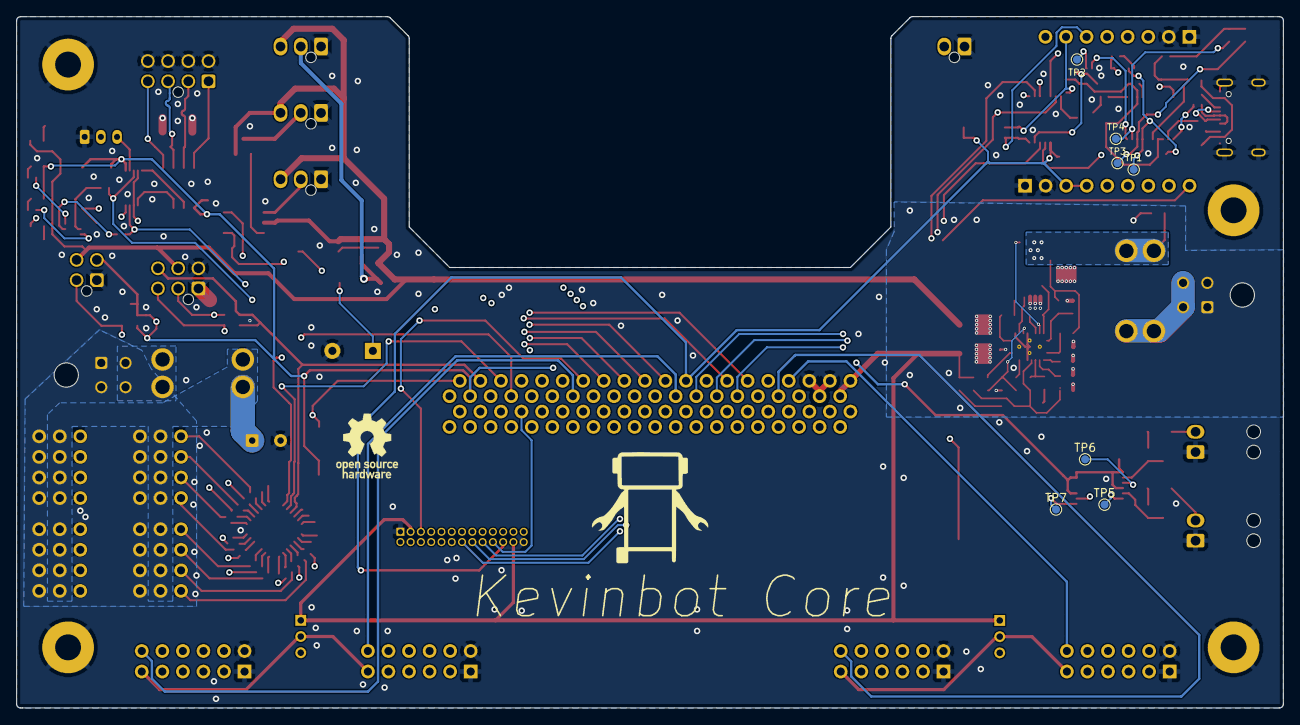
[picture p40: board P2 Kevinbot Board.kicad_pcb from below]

Board: 4 copper layers, 156.5 x 85.4 mm, 165 parts (8 on the bottom side), 192 nets.

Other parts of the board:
G1, G2: LOGO; Kevinbot15mm

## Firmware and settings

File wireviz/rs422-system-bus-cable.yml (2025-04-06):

connectors:
  System:
    type: "Molex Nano-Fit 2x8 1053081208 "
    subtype: female
    pinlabels: [R+, R-, D+, D-, GND, GND, GND, GND]

  Core:
    type: "Molex Nano-Fit 2x8 1053081208 "
    subtype: female
    pinlabels: [R+, R-, D+, D-, GND, GND, GND, GND]

cables:
  Cable:
    category: bundle
    colors: [GN, BU, YE, OG, BK]
    gauge: 22 AWG
    length: 0.2
    color_code: DIN
    wirecount: 5
    shield: SN
    image:
      src: images/empty.png
      caption: R+/R- and D+/D- are twisted pairs

  Resistor1:
    category: signal
    gauge: 100 Ohm
    colors: [GN, BU]
    length: 0.01
    wirecount: 2
    show_wirecount: false

  Resistor2:
    category: simple
    gauge: 100 Ohm
    colors: [YE, OG]
    length: 0.01
    wirecount: 2
    show_wirecount: false

connections:
  -
    - System: [1, 2, 3, 4, 5, 6, 7, 8]
    - Cable:  [1, 2, 3, 4, 5, 5, 5, 5]
    - Core:   [3, 4, 1, 2, 5, 6, 7, 8]

  -
    - System: 8
    - Cable: s

  -
    - System: [1, 2]
    - Resistor1: [1, 2]

  - 
    - Resistor2: [1, 2]
    - Core : [1, 2]

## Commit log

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2023-02-26 Replace I2C headers with JST
    [P2 Kevinbot Board.kicad_pcb, P2 Kevinbot Board.kicad_sch, i2c.kicad_sch]
2023-02-26 Fix DRC Warnings
    [P2 Kevinbot Board.kicad_pcb]
2023-02-26 Move screw holes, move serial port to top
    [P2 Kevinbot Board.kicad_pcb]
2023-02-26 Add I2C Expander with MPU2950
    [i2c_exapnder.kicad_pcb, i2c_exapnder.kicad_sch]
2023-02-26 Add 3D model to power jack
    [P2 Kevinbot Board.kicad_pcb]
2023-02-27 Align I2C Expander screw holes
    [i2c_exapnder.kicad_pcb]
2023-02-27 Update Board Settings on I2C Expander
    [i2c_exapnder.kicad_pcb]
2023-03-06 Add logo and text to I2C Expander
    [P2 Kevinbot Board.kicad_pcb, i2c_exapnder.kicad_pcb, i2c_exapnder.kicad_sch]
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2023-05-07 Redesign for SMD and new pinmap
    [P2 Kevinbot Board.kicad_pcb, P2 Kevinbot Board.kicad_sch, leds.kicad_sch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]
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2023-05-20 Add motor driver conns, pinout changes
    [P2 Kevinbot Board.kicad_pcb, P2 Kevinbot Board.kicad_sch]
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2023-05-20 Place buzzer
    [P2 Kevinbot Board.kicad_pcb]
2023-05-20 Serial and EXT reset
    [P2 Kevinbot Board.kicad_pcb]
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2024-06-21 Make space for second servo connector row
    [P2 Kevinbot Board.kicad_pcb]
2024-06-22 Make power led smd 0603
    [P2 Kevinbot Board.kicad_pcb, P2 Kevinbot Board.kicad_sch]
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2024-06-22 Add servo power indicator
    [P2 Kevinbot Board.kicad_pcb, servo.kicad_sch]
2024-06-22 Fix global labels
    [P2 Kevinbot Board.kicad_pcb, P2 Kevinbot Board.kicad_sch, i2c.kicad_sch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]
2024-06-22 Almost finish 2nd pca
    [P2 Kevinbot Board.kicad_pcb, servo.kicad_sch]
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2024-06-23 Add int buzzer enable jumper
    [P2 Kevinbot Board.kicad_pcb, P2 Kevinbot Board.kicad_sch]
2024-06-23 Add ext buzzer fet and connector
    [P2 Kevinbot Board.kicad_pcb, P2 Kevinbot Board.kicad_sch]
2024-06-24 Add servo fuse, increase trace width
    [P2 Kevinbot Board.kicad_pcb, P2 Kevinbot Board.kicad_sch]
2024-06-24 Add new kevinbot logo
    [P2 Kevinbot Board.kicad_pcb, P2 Kevinbot Board.kicad_sch, leds.kicad_sch]
2024-06-24 Change pca section rects
    [P2 Kevinbot Board.kicad_pcb]
2024-06-28 Change logo, led resistors
    [P2 Kevinbot Board.kicad_pcb, P2 Kevinbot Board.kicad_sch]
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2024-06-28 DRC fixes, add missing library, misc
    [P2 Kevinbot Board.kicad_pcb, P2 Kevinbot Board.kicad_sch, i2c.kicad_sch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]
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2024-06-29 Add mfr part numbers and datasheets to all
    [P2 Kevinbot Board.kicad_pcb, P2 Kevinbot Board.kicad_sch, i2c.kicad_sch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]
2024-06-29 Add rx/tx leds, schematic cleanup
    [P2 Kevinbot Board.kicad_pcb, P2 Kevinbot Board.kicad_sch]
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2024-06-30 Swap Serial pinout
    [P2 Kevinbot Board.kicad_pcb, P2 Kevinbot Board.kicad_sch]
2024-06-30 Swap rst and buz pinouts
    [P2 Kevinbot Board.kicad_pcb, P2 Kevinbot Board.kicad_sch]
2024-06-30 initial relocation of pca, re-order servo connectors
    [P2 Kevinbot Board.kicad_pcb, P2 Kevinbot Board.kicad_sch, i2c.kicad_sch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]
2024-06-30 Fix incorrect resistor part numbers
    [P2 Kevinbot Board.kicad_pcb, servo.kicad_sch]
2024-06-30 Add servo filtering cap
    [P2 Kevinbot Board.kicad_pcb, P2 Kevinbot Board.kicad_sch]
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2024-06-30 Fix incorrect resistor value
    [P2 Kevinbot Board.kicad_pcb, P2 Kevinbot Board.kicad_sch, servo.kicad_sch]
2024-08-12 Use mosfet for internal buzzer
    [P2 Kevinbot Board.kicad_pcb, P2 Kevinbot Board.kicad_sch]
2024-08-12 Add ground test posts
    [P2 Kevinbot Board.kicad_pcb, P2 Kevinbot Board.kicad_sch]
2024-08-22 Remove incorrect p2 3d model
    [P2 Kevinbot Board.kicad_pcb]
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2024-08-23 Silkscreen changes, DRC, make ground pin 1 for more conns
    [P2 Kevinbot Board.kicad_pcb, P2 Kevinbot Board.kicad_sch, leds.kicad_sch]
2024-08-24 Writerside docs, test points for P33, P32
    [P2 Kevinbot Board.kicad_pcb, P2 Kevinbot Board.kicad_sch, writerside.cfg]
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2024-08-26 Writerside changes, pcb expansion conn
    [P2 Kevinbot Board.kicad_pcb, P2 Kevinbot Board.kicad_sch]
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2024-08-29 Fix major mosfet wiring error
    [P2 Kevinbot Board.kicad_pcb, P2 Kevinbot Board.kicad_sch, leds.kicad_sch]
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2024-08-31 Maybe fix gh actions 2
    [writerside.cfg]
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2024-09-04 Via stitching, ground plane islanding
    [P2 Kevinbot Board.kicad_pcb]
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2024-09-14 Add open source certification mark
    [P2 Kevinbot Board.kicad_pcb]
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2024-10-15 Use tc4427 for RSL OUT, first commit for RevB
    [P2 Kevinbot Board.kicad_pcb, leds.kicad_sch]
2024-10-15 Swap servo power pins
    [P2 Kevinbot Board.kicad_pcb, P2 Kevinbot Board.kicad_sch]
2024-11-09 Add P2 Edge Slot 3d Model
    [P2 Kevinbot Board.kicad_pcb]
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2024-12-24 fix buzzer fet
    [P2 Kevinbot Board.kicad_pcb, P2 Kevinbot Board.kicad_sch]
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2025-01-10 Swap tx/rx conn labels
    [P2 Kevinbot Board.kicad_pcb]
2025-03-25 Remove all components, redo board outline
    [CardEdge80p127_RA_TH_10156.step.stp, P2 Kevinbot Board.kicad_pcb, P2 Kevinbot Board.kicad_sch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]
2025-03-27 Mostly routed accessory headers
    [436500200--3DModel-STEP-455599.STEP, 64005-RevA-P2-PrototypeBoard-Addon.step, P2 Kevinbot Board.kicad_pcb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]
2025-03-28 Begin work on usbc programmer, misc
    [P2 Kevinbot Board.kicad_pcb, P2 Kevinbot Board.kicad_sch, prog.kicad_sch]
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2025-04-04 Add leds, docs cleanup
    [P2 Kevinbot Board.kicad_pcb, P2 Kevinbot Board.kicad_sch, led.kicad_sch]
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2025-04-05 docs: add logo banner, pcb: reset text changes
    [P2 Kevinbot Board.kicad_pcb]
2025-04-06 pcb, sch: add rs422 comm interface
    [1053101108--3DModel-STEP-510211.STEP, P2 Kevinbot Board.kicad_pcb, P2 Kevinbot Board.kicad_sch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]
2025-04-06 pcb, sch: add transciever decoupling cap, docs, wireviz: add rs422 wiring harness
    [P2 Kevinbot Board.kicad_pcb, rs422.kicad_sch]
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2025-04-06 pcb, sch: mounting holes
    [P2 Kevinbot Board.kicad_pcb, P2 Kevinbot Board.kicad_sch]
2025-04-06 rs422, pcb: uart/rs422 mux
    [P2 Kevinbot Board.kicad_pcb, rs422.kicad_sch]
2025-04-09 docs: add wire info, psu: add connector, i2c: initial work, lots of changes
    [1053101106--3DModel-STEP-510211.STEP, 430450400--3DModel-STEP-56544.STEP, P2 Kevinbot Board.kicad_pcb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]
2025-04-09 cad: fix molex conn colors
    [1053091102--3DModel-STEP-510211.STEP, 1053091103--3DModel-STEP-510211.STEP, 1053101106--3DModel-STEP-510211.STEP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]
2025-04-09 sch, pcb: update pn fields
    [P2 Kevinbot Board.kicad_pcb, P2 Kevinbot Board.kicad_sch, buzzout.kicad_sch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]
2025-04-11 prog, pcb: test points
    [P2 Kevinbot Board.kicad_pcb, prog.kicad_sch]
2025-04-11 prog, pgmmux, sch: hierarchical organization, prep for programmer mux
    [P2 Kevinbot Board.kicad_pcb, P2 Kevinbot Board.kicad_sch, pgmmux.kicad_sch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]
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2025-04-13 docs: add ibom, pcb, psu: fuse, pgmmux, pcb: 2.00mm headers -> 2.54
    [P2 Kevinbot Board.kicad_pcb, P2 Kevinbot Board.kicad_sch, pgmmux.kicad_sch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]
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2025-04-13 sym: TMUX1511, psu: add failsafe development
    [P2 Kevinbot Board.kicad_sch, psu.kicad_sch]
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2025-04-14 i2c, servo, pcb: pca9685 servo, pcb, rs422: leds
    [P2 Kevinbot Board.kicad_pcb, i2c.kicad_sch, owx.kicad_sch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]
2025-04-14 buzzout, pcb: use dip switch for buzzer enable, pcb: servo output pin labels
    [P2 Kevinbot Board.kicad_pcb, buzzout.kicad_sch]
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2025-04-15 rs422, led, pcbs: status leds, readme: add image
    [P2 Kevinbot Board.kicad_pcb, P2 Kevinbot Board.kicad_sch, led.kicad_sch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]
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2025-04-23 pcb, buck: cleanup, add 7070 inductor DNP footprint
    [P2 Kevinbot Board.kicad_pcb, buck.kicad_sch]
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2025-07-11 part number fix
    [P2 Kevinbot Board.kicad_sch, buck.kicad_sch]
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
